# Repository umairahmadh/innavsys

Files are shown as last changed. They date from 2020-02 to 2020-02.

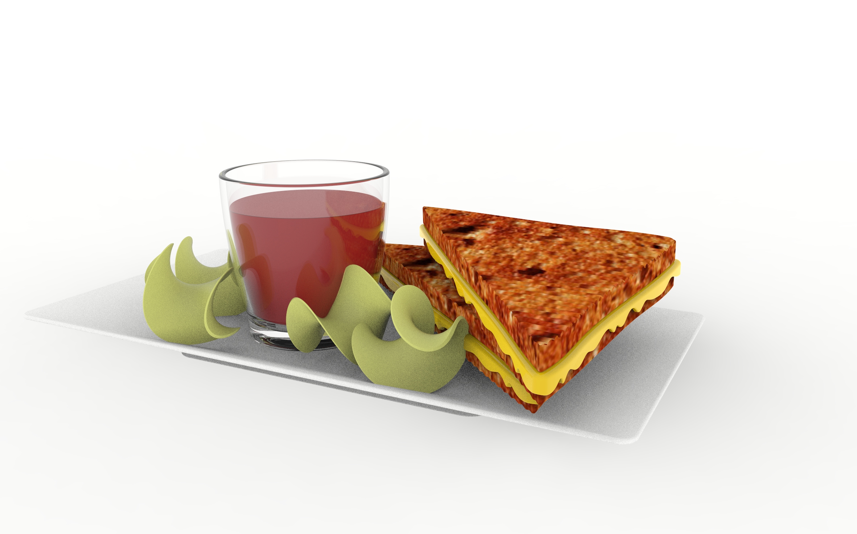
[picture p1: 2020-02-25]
Hardware/Robot_design/grilled-cheese-plate-1.snapshot.2/untitled.37.jpg

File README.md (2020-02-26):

# innavsys
External vision based navigation system for Indoor robots

This project was done for the fulfilment of the degree program "BSc (Hons) Engineering in Electrical and Electronic Engineering" at Faculty of Engineering, South Eastern University of SRi Lanka.

The team was consisting of the following students,
1) G.S. Umair Ahmadh (https://github.com/umairahmadh | https://www.linkedin.com/in/umairahmadh )
2) I.I.S. Premasri ( https://www.linkedin.com/in/imeshsps/ )
3) A.N.F. Mursina Begum ( https://www.linkedin.com/in/mursina-begum-606090127/ )

And the supervisors were,
1) Dr. WGCW. Kumara
2) Eng, Abdul Cadar

Project documentations and descriptions are in reports folder.

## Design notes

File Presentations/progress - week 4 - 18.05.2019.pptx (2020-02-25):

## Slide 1

EE 74099 / EN 74099 Research Project
Project Title: Vision Based Navigation System for Indoor Robots

Progress Presentation – 4
18.05.2019

Under the Supervision of :
Dr. WGCW Kumara
And Eng. Abdul Cadar

Team Members:
ANFM. Begum - SEU/IS/13/EG/002
GSU. Ahmadh - SEU/IS/13/EG/011
IIS. Prema Sri - SEU/IS/13/EG/032

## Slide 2

We are now mainly working in two parts.
1. Hardware build of the robot
2. Navigation System

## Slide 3

As we already reported in the previous progresses, we managed to come to an extent where we are now able to transfer a coordinate from a camera image to a real 2D map.
When we complete the part of detecting and tracking the robots in the image, we will then be able to plot the coordinates on the Map drawn.

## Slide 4

At this point, it requires a lot of reading on Object detection and tracking.
There are many recommended ways to achieve this. Traditional image processing methods are being outperformed by Deep learning.

Now we need to study about the possible methods and to decide on which way to move with.

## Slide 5

Imesh’s proposed design for the Robot will be as follows in the next slides,

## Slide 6

Robot-building…

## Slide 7

- A mobile robot needs locomotion mechanisms that enable it to move unbounded throughout it’s environment.
- Mobile robots generally locomote either using wheeled mechanisms, or using a small number of articulated legs.
- Legged locomotion requires higher degrees of freedom and therefore greater mechanical complexity than wheeled locomotion.
- Wheels, in addition to being simple, are extremely well suited to flat ground.

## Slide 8

- There are four major wheel classes.
  1. Standard wheel.
  2. castor wheel.
  3. Swedish wheel.
  4. Ball or spherical wheel.

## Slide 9

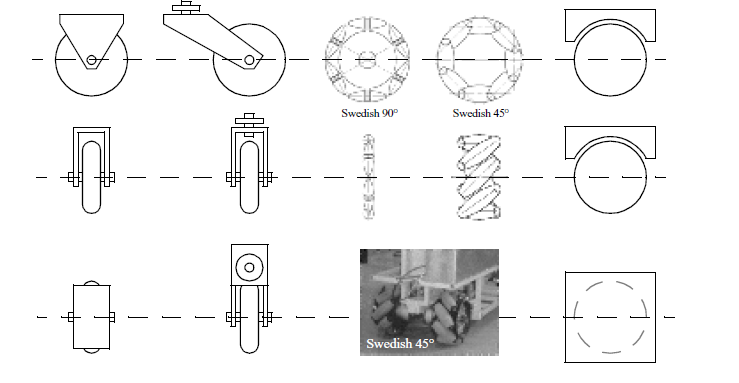
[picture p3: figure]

1

2

3

4

Source : Introduction to Autonomous Mobile Robots - Siegwart Nourbakhsh (Figure 2.19)

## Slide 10

- There is a very large space of possible wheel configurations when considers possible techniques for mobile robot locomotion.
- The choice of wheel types for a mobile robot is strongly linked to the choice of wheel arrangement, or wheel geometry.
- One of the cost effective solution for mobile robot navigation is differential drive systems.

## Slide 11

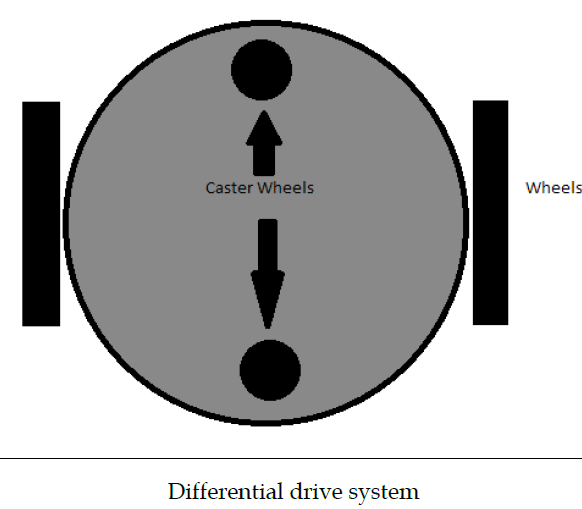
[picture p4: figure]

Source : semanticscholor.org

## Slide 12

- The differential drive robot consists of two wheels mounted on a common axis controlled by two separate motors.
- This drive mechanism is mainly indented for indoor navigation.
- There are two caster wheels ensures the stability and weight distribution of the robot.

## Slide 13

Some of out preliminary works on object detection is in the following few slides…

## Object tracking

Two main procedures are used in object tracking
- Color filtering
- Contour finding

## Steps followed in coding

1. Convert image from BGR to HSV
2. Filter the pixels between minimum and maximum threshold
3. Morphological Operations (Dilate and Erode)
4. Track the (x,y) coordinates of object.

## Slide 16

Original image is converted from BGR to HSV

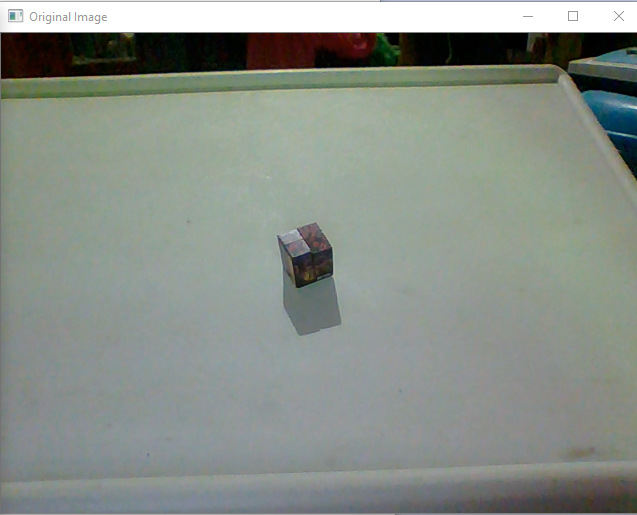
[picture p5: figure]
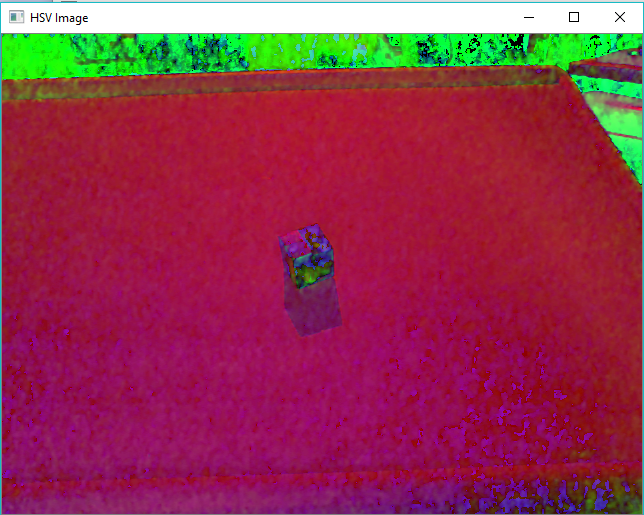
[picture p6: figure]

Figure 1: BGR image

Figure 2: HSV image

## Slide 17

Threshold image is obtained from HSV adjustment

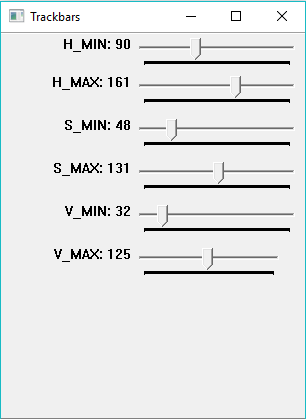
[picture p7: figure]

Figure 2: HSV values

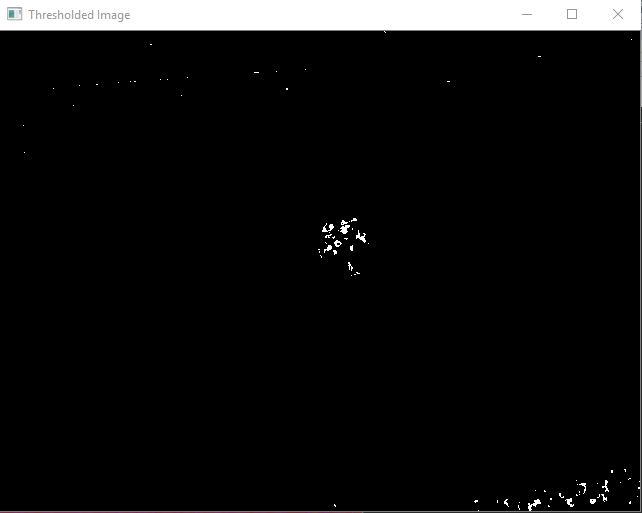
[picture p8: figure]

Figure 3: Threshold Image

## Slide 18

Dilate and erode functions are used to reduce noise

Figure 1: Adjusted HSV values

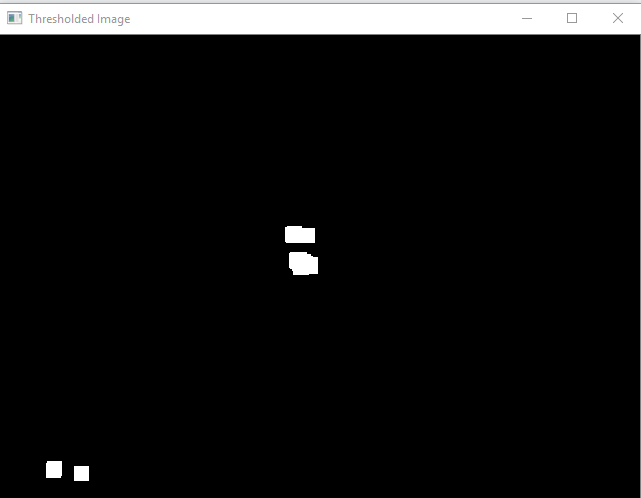
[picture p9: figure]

Figure 1: Threshold Image after morphological operations

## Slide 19

Object is tracked by largest contour

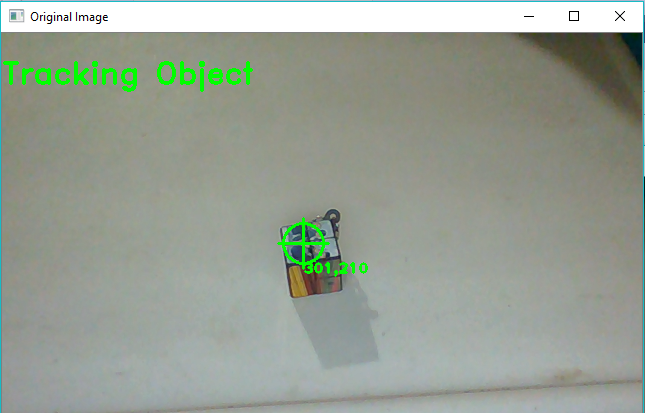
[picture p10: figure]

Figure 4: Tracked object

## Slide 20

Thank You

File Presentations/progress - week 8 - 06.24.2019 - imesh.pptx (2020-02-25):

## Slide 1

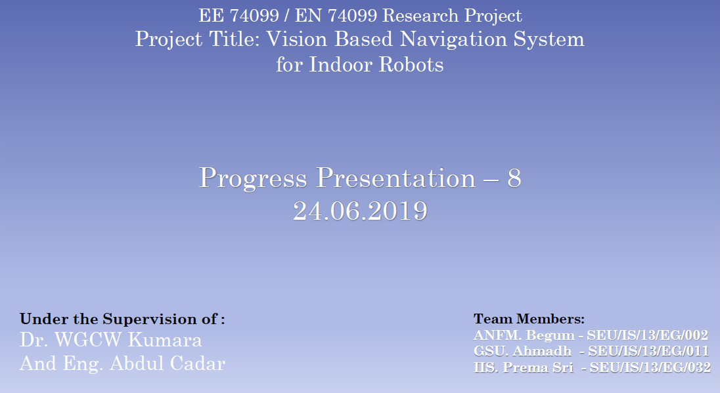
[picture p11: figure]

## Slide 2

This week we worked on,
- Designing Robot model
- Total Weight estimation
- Idea for Path planning based on External camera
- Mapping and Navigation with ROS

## Designing Robot model

- We did a Solidworks model for the Robot design we are planning to build.
- For the plates we decided to go with Aluminum Composite Material boards because of their strength and light weight.
- To connect plates we will be using threaded rods covered by aluminum tubes.

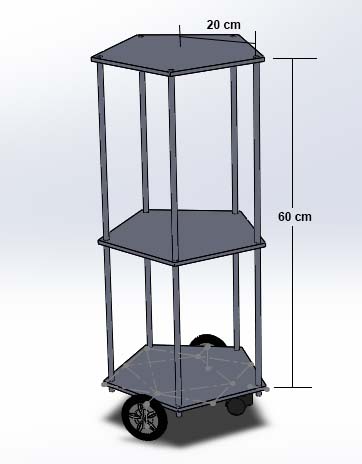
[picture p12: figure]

## Total Weight Estimation

Item | Weight
ACM Board for 0.378 m² area | 1.52 kg
Threaded rods for 3.5 m | 2.2 kg
Kinect | 0.6 kg
Aluminum tubes | 0.4 kg
Wheels | 0.6 kg
Power Bank and Battery | 1.0 kg
Motors (NEMA 23) x 2 | 1.4 kg
Other Electronics | 0.5 kg
For foods | 1.0 kg
Total Weight | 9.22 kg

## Calculation of motor torque

- In our design we have 4 wheels and 2 motors.
- Here we assume that the coefficient of friction is 0.6 and radius of wheel is 5 cm.
- The weight acting on the four wheels can be written as,

- N1 is the weight acting on each caster wheel.
- N2 on each motor wheel.

2 ∗ N1 + 2 ∗ N2 = Total Weight

The maximum torque is required when the robot starts moving. It should also overcome friction.
To calculate the maximum torque (T),

μ ∗ N ∗ r − T = 0

- μ is the coefficient of friction.
- N is the average weight acting on each wheel.
- r is the radius of wheels.
- T is the torque.

## Calculation of motor torque

- Assuming that the weight of the robot is equally distributed on all the four wheels,

N = mg / 4

=22.6 N

=9.22 kg ×9.8ms^(−2) / 4

Motor torque required,

T = 0.6 ∗ 22.6N ∗ 0.05 m

= 0.678 N m

## Idea for Path planning based on External camera

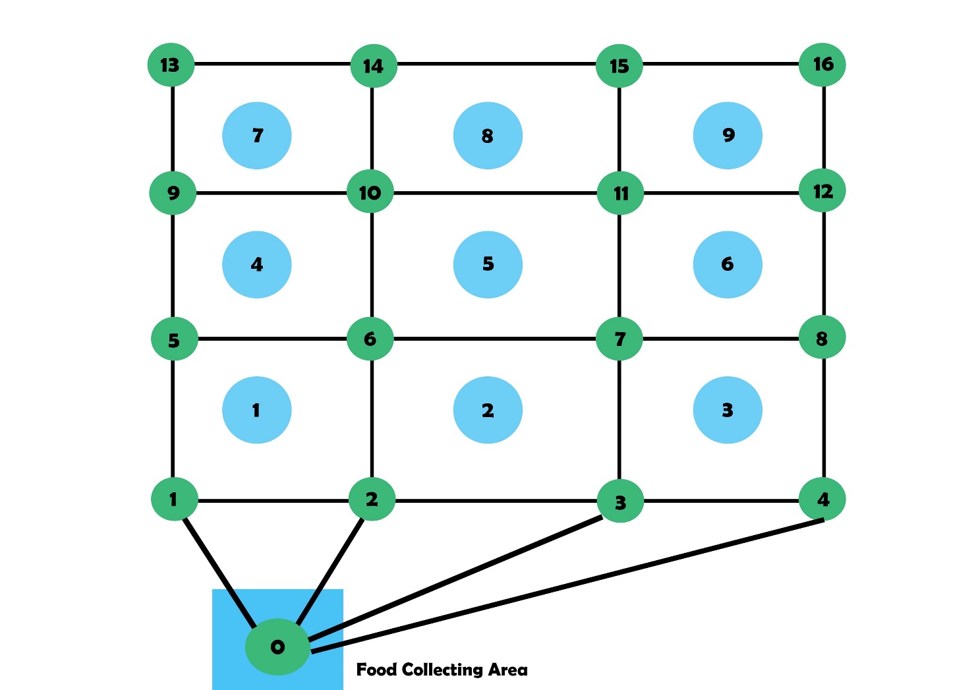
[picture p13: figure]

## Idea for Path planning based on External camera

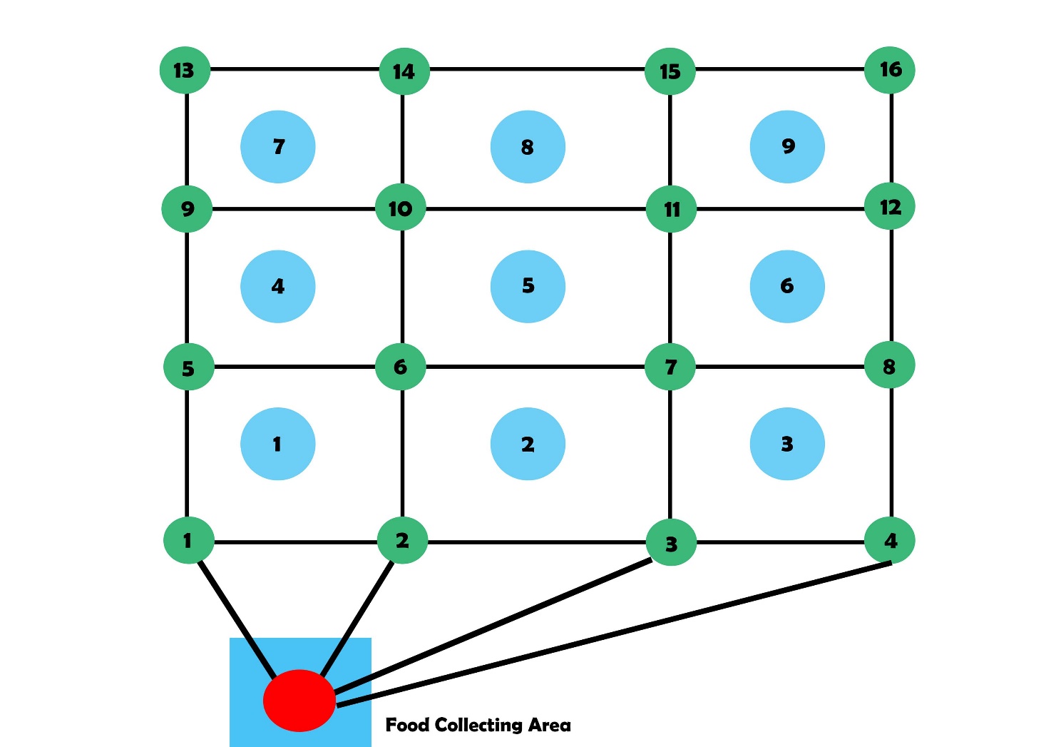
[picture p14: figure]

## Idea for Path planning based on External camera

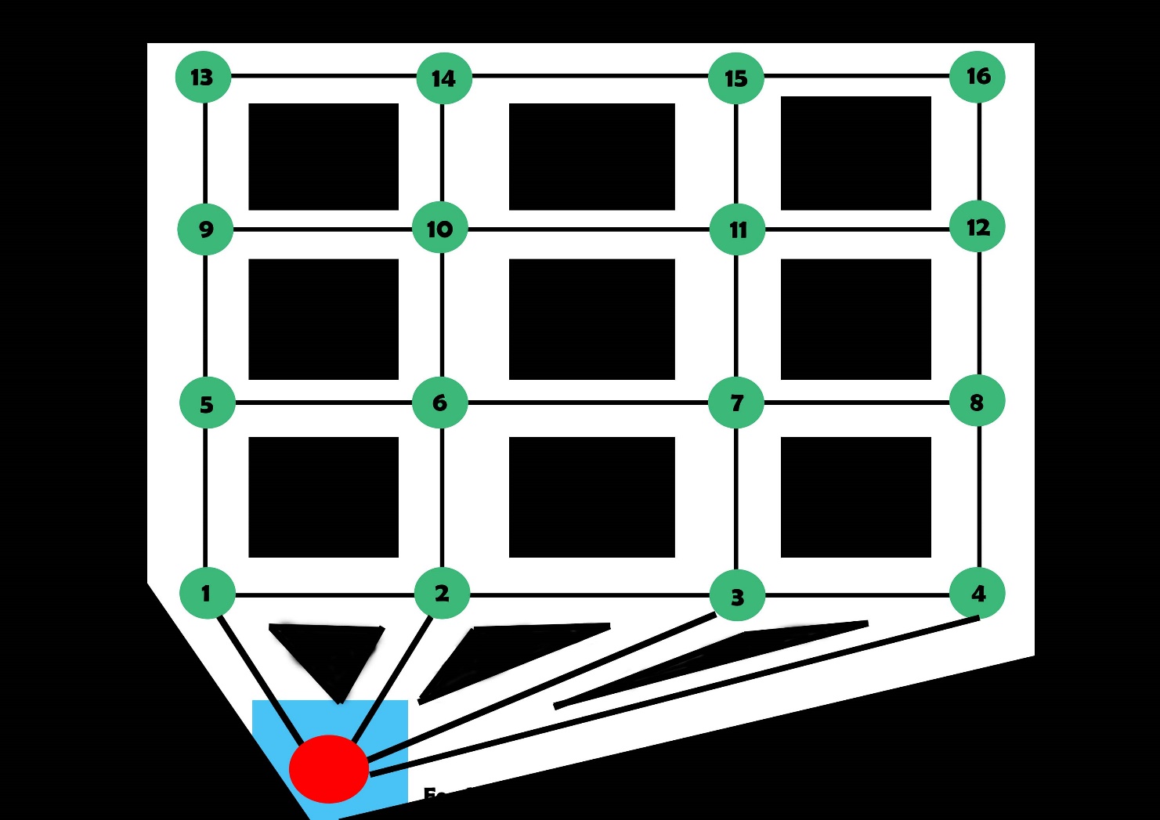
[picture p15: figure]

## Idea for Path planning based on External camera

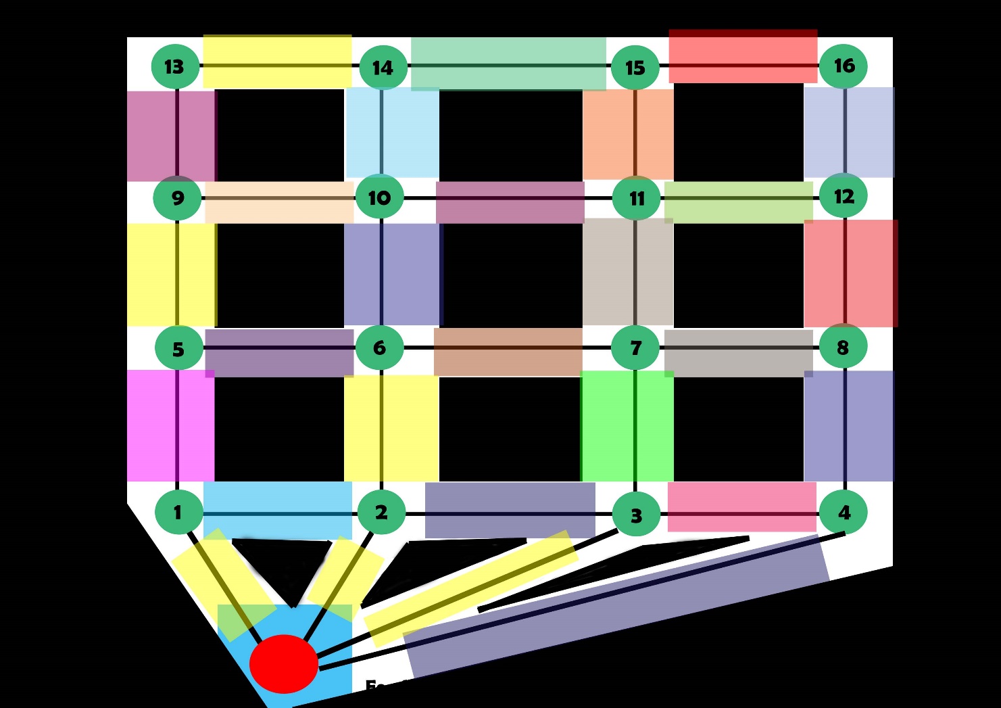
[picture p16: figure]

## Idea for Path planning based on External camera

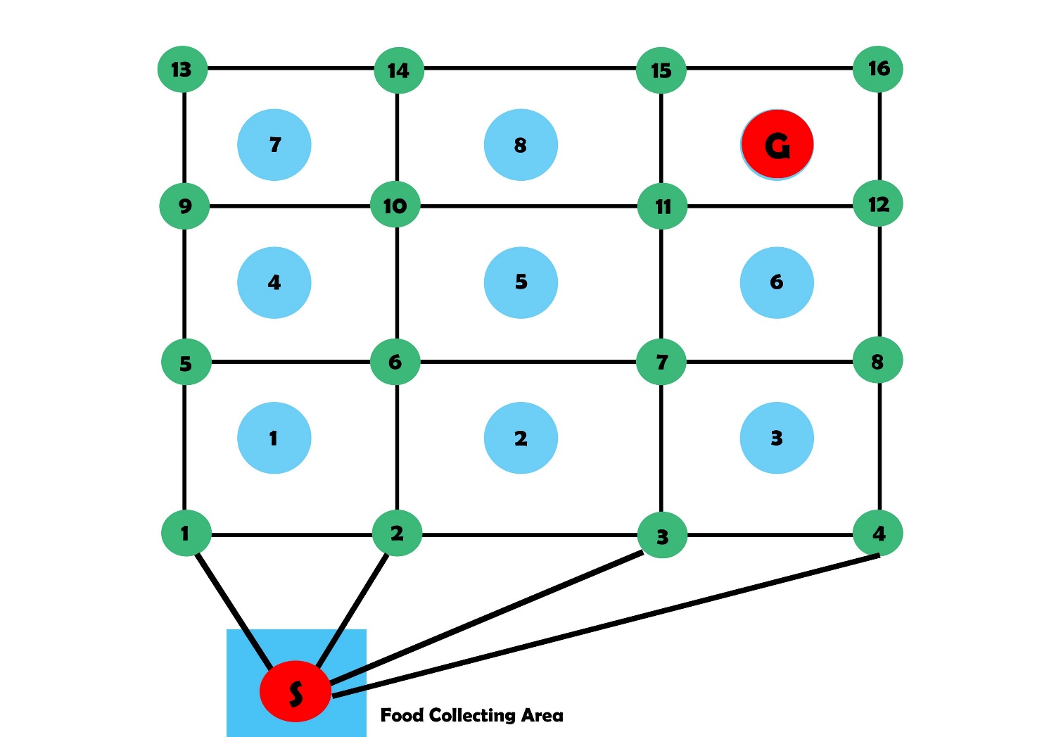
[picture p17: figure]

## Idea for Path planning based on External camera

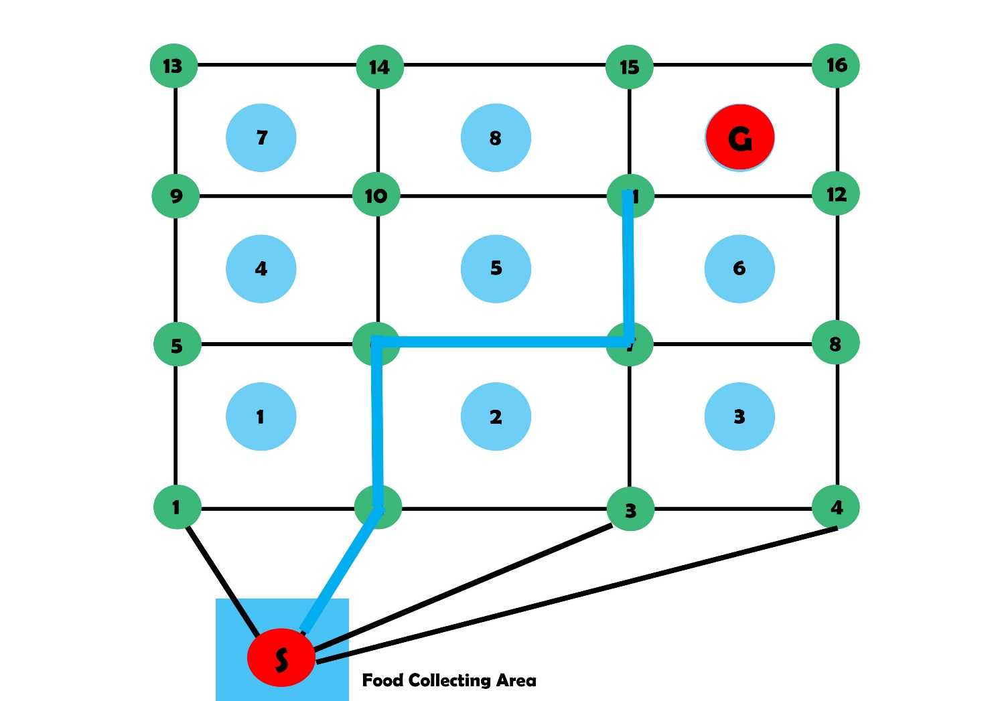
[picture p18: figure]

## Idea for Path planning based on External camera

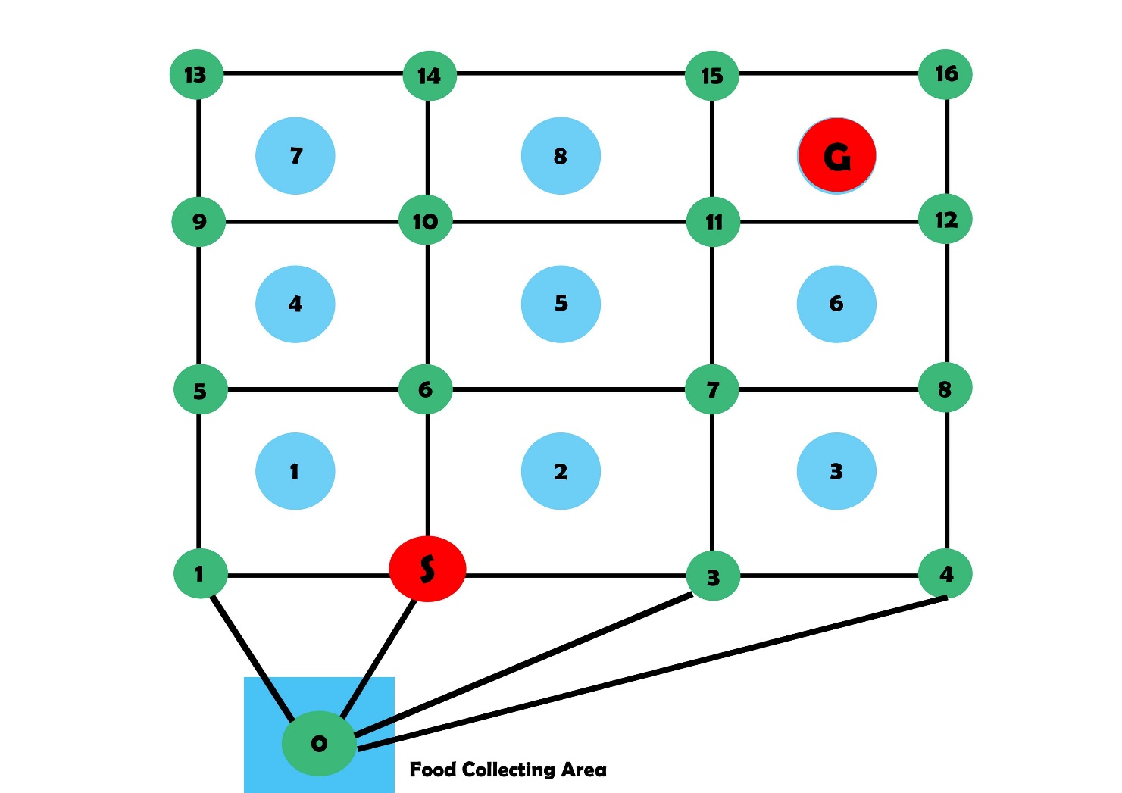
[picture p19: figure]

## Idea for Path planning based on External camera

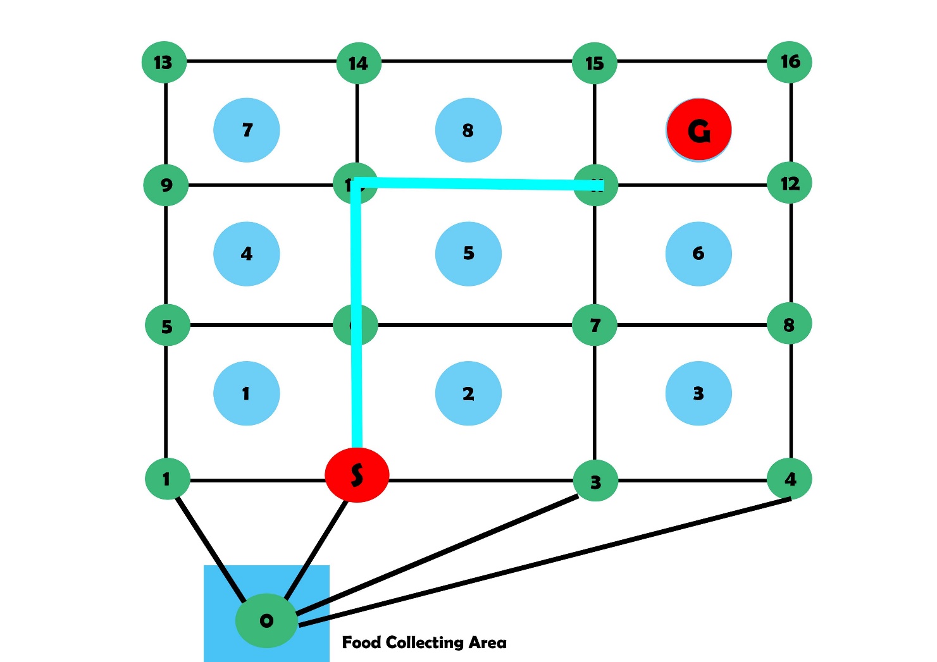
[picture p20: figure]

## Idea for Path planning based on External camera

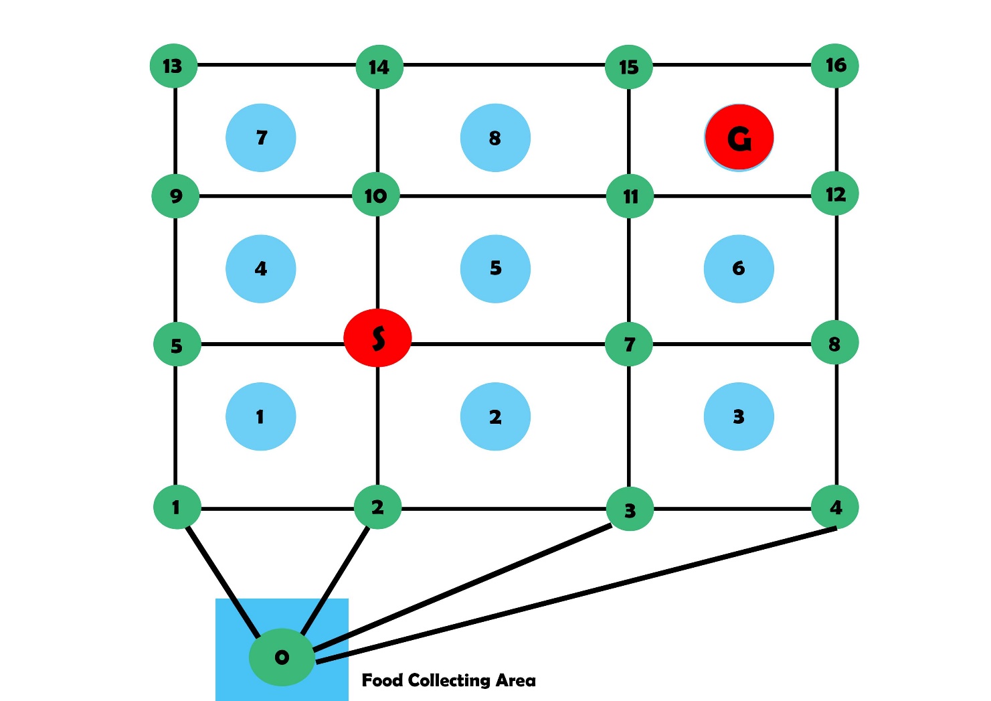
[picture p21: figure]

## Idea for Path planning based on External camera

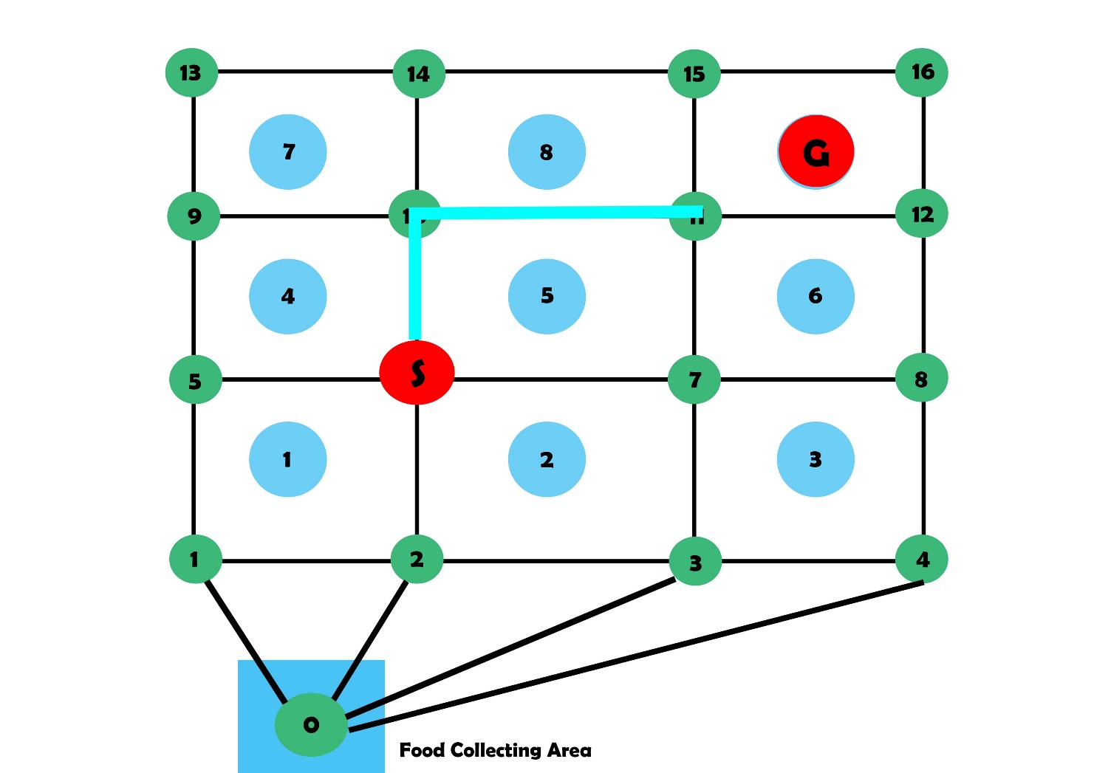
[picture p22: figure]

## Idea for Path planning based on External camera

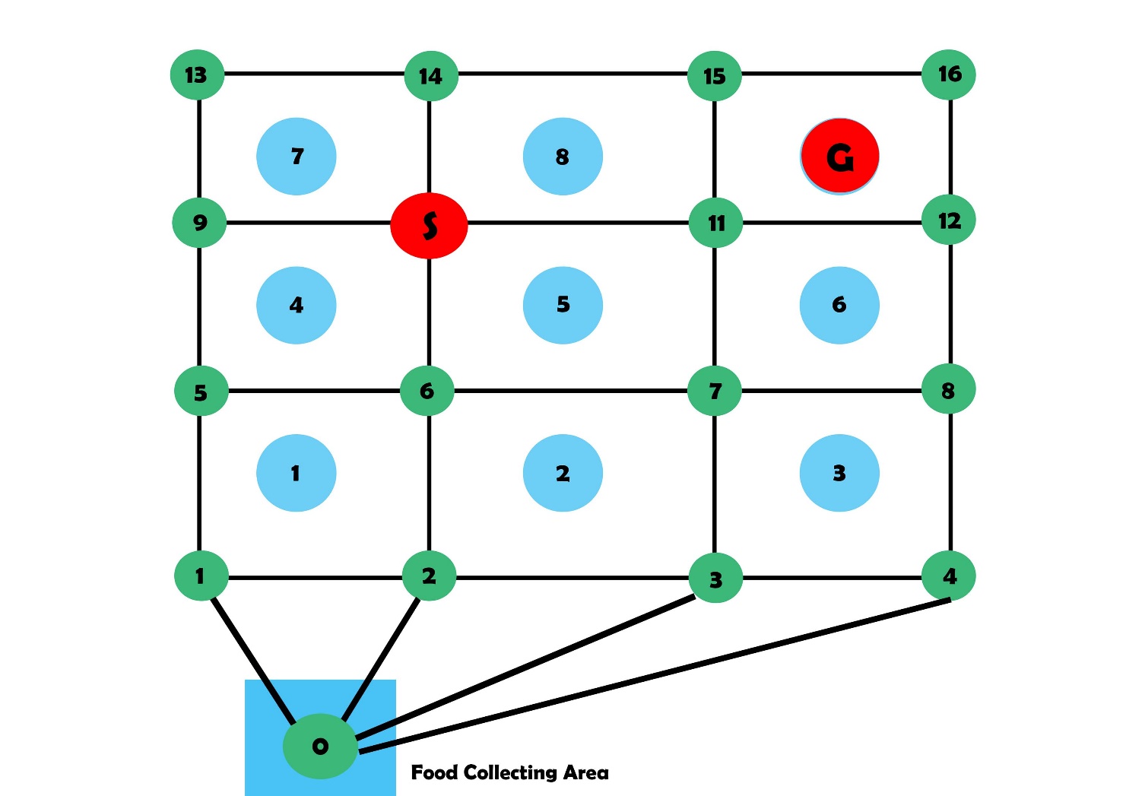
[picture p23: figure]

## Idea for Path planning based on External camera

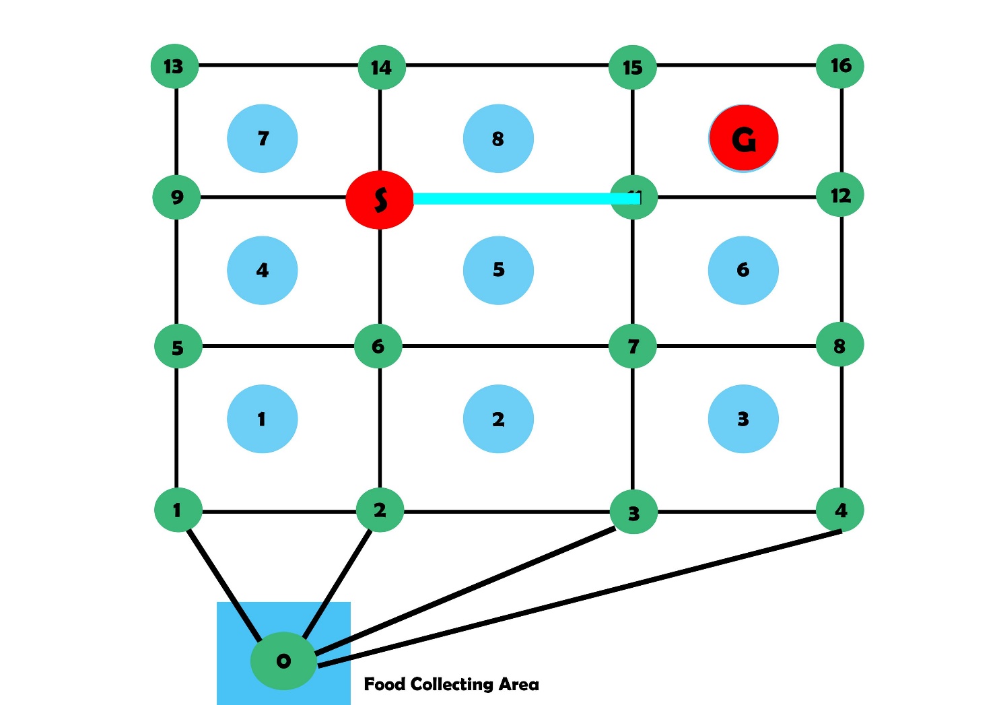
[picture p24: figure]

## Idea for Path planning based on External camera

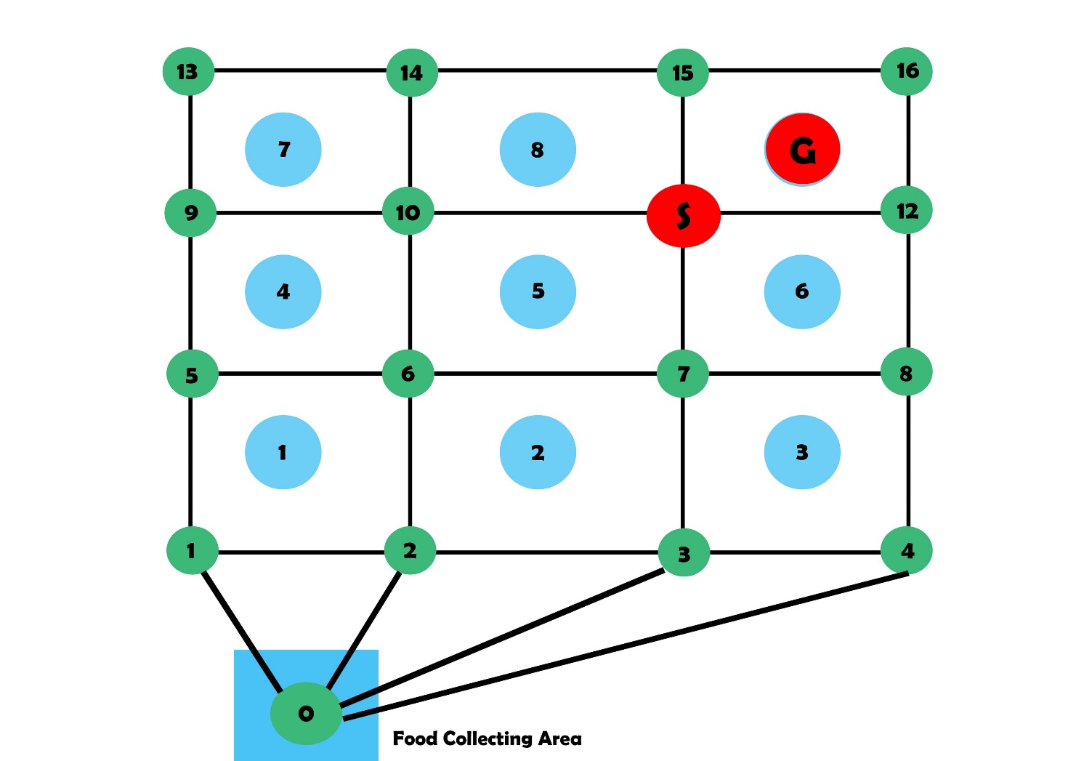
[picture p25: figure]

## Mapping and Navigation with ROS

- https://youtu.be/u9l-8LZC2Dc

## For Next Week..

- Buying items and start building the robot
- Recording footages of canteen
  - Stitching images from multiple camera
  - Tracking moving objects on the path
  - Plotting the tracked objects to the map and do path planning for the robot
- UI design and Database schema for Order management system
  - Implementation of the system on a local web server

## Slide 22

Thank You

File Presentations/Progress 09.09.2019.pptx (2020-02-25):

## Phase 1: Hardware build of the robot

Progress - 09.09.2019

Team:
ANFM. Begum - SEU/IS/13/EG/002
GSU. Ahmadh - SEU/IS/13/EG/011
IIS. Prema Sri - SEU/IS/13/EG/032

## Last meeting:

- We agreed to work on finishing the robot hardware as it is important to continue other parts of the project.
- We managed to finish the robot skeleton and making wheel alignments with the motor. Due to exams, we didn’t get to work on motor controlling and the electronics of it.

## Robot building

1. Building shaft and coupler for wheel-motor connection

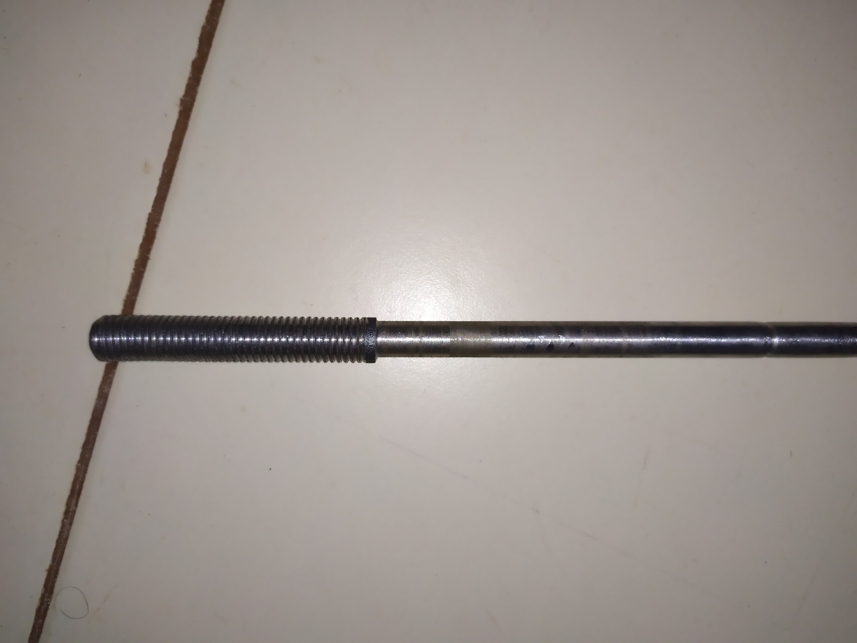
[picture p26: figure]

## Robot building


2. Selection and purchasing of the wheel and connection
3. Adding pair of bearings for the shaft alignment and support
4. Mounting them to the robot body

## Robot building


5. Caster Wheel selection and purchasing
6. Mounting the wheels to the body with spacer nuts to align with the wheel height

## Robot building


7. Connecting the entire skeleton and completing the body
Note: Image here is the initial built of the robot. Later we did motor upgrade and wheel changes, unable to get the final image.

## Next progress:

- Already gathered robot electronics will be connected to the body and we will make the controls.
- By having a wireless control to the robot, any movement commands sent to the robot will be programmatically analyzed and the motor control will be done. (As in our entire system, navigation system will send the movement commands and the robot will only receive which directing and how long it should move. All other coordinate process is to be handled by our external navigation system

## Some interim progress on the electronics


## Thank You

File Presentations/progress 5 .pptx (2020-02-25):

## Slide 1

EE 74099 / EN 74099 Research Project
Project Title: Vision Based Navigation System for Indoor Robots

Progress Presentation – 5
16.05.2019

Under the Supervision of :
Dr. WGCW Kumara
And Eng. Abdul Cadar

Team Members:
ANFM. Begum - SEU/IS/13/EG/002
GSU. Ahmadh - SEU/IS/13/EG/011
IIS. Prema Sri - SEU/IS/13/EG/032

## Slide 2

Design for the robot
Detection and tracking of the robot

1

2

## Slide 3

Design for the robot…

## Robot chassis design

- The design we choose should be able to hold electronics components such as microcontrollers, sensors, battery and hold food we need to deliver.
- One of the easiest designs to satisfy these requirements is TurtleBot, which has kind of table-like design.

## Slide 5


- It has three layers in the chassis.
- A robot platform called Roomba is the drive mechanism of this platform.
- We are planning to design a robot similar to this with our own moving platform and components.
- Moving platform will be designed as a differential drive system.

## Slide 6

Tracking of Robot
Using Object Detection

## Tracking of Robot

- For the navigation of the robot, we need two things.
  1. Object Detection : To identify the current position of the robot
  2. Tracking the path : To track the movements of robot to make sure it is aligned to the commands that being sent to it to reach the target destination.


## 1. Object Detection

- We need to use object detection in our project to achieve two things.
  I. Get the location of the robot in the map to help localize robot in the environment.
  II. Identify people in the environment to decide on the best path for the robot to reach the destination.
- At first step, we are planning to start working on identifying robot in a video feed and get the location in the image. And the detection of the moving objects will be proceeded later on the course.

## 1. Object Detection

- For Object detection,
  - Currently we are experimenting with different methods.
  - Deep learning based object detection is the first one that we are going to go with.
  - In order to do the detection, we need to train a neural network with many images of the robot to identify it on the image feed.
  - As we currently don’t have a robot we thought to go with a simulation images to train it and to test the detection and hence the tracking in the video generated from the simulation.

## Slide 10

- To achieve real-time object detection, we’ll need to..
  - Access video stream in an efficient manner.
  - Apply object detection to each frame.
- Accessing video stream is possible with OpenCV.
- To achieve object detection, we need to train an image classifier.
- Then we can use trained classifier to detect objects in an image, and to track them across a video.

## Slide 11

- we are going to test an image classifier with the images we have from simulation model for the TurtleBot robot from Gazebo robotics simulator.


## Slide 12

Next Week…

## Next Week

- We will be working on training a neural network with images gathered from the simulation environment.
- After successfully completing the training, we will then work on integrating the detection to OpenCV to get the coordinates of the robot on the image.
- Then, converting the image coordinates to world coordinates using our previously done works. So that we will have a tracking on a 2D map.

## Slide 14

Thank You

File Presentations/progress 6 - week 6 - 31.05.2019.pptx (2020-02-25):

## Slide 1

EE 74099 / EN 74099 Research Project
Project Title: Vision Based Navigation System for Indoor Robots

Progress Presentation – 6
31.05.2019

Under the Supervision of :
Dr. WGCW Kumara
And Eng. Abdul Cadar

Team Members:
ANFM. Begum - SEU/IS/13/EG/002
GSU. Ahmadh - SEU/IS/13/EG/011
IIS. Prema Sri - SEU/IS/13/EG/032

## Object detection using deep learning

- Predict the object along with the class is called object detection.
- From object detection we can predict class and bounding box’s coordinates. Using those coordinates, we can identify the location of object.


Figure 1: Objects with their label and bounding box

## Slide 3

To detect the image using classification, below steps will be followed
1. Train a multi-label classifier
2. Take windows of fixed sizes from input image
3. Feed the windows to the image classifier to further process.
- There are various object detection methods,
1. SIFT
2. HOG features
3. R-CNN
4. YOLO
5. SSD

## Object detection with SIFT feature extractor

- Stands for Scale Invariant Feature Transform
- We can work with single sample image in SIFT.
- Steps followed to get object detection
1. Get features from training image(sample image) and query image(live image from camera)
2. Match the parameters of both images which are extracted by SIFT(). We can set minimum match count.
3. If we get good matches, create a border around the object.

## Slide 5


Figure 2: Train Image


Figure 3: Query Image

## Video object tracking

- We can’t use object detection in each frame when image has multiple objects. Connecting the objects in the frames will be difficult for it.
- Also if the object goes out of the camera view, we can’t detect and ensure the same object.

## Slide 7

- Object tracking process consists four components,
1. Target Initialization
We have to define the starting point of the target by drawing a boundary around it
2. Appearance Modelling
We need to know about material and visual features
3. Motion estimation
Predict the zone where the object will be presented in next frames
4. Target positioning
Use motion estimation’s region to get the exact location of object
- Most popular deep learning based approaches
1. MDNET
2. GOTURN
3. ROLO

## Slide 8

Currently we are learning and experimenting various methods to be used in detecting and tracking our robot.
Accuracy and robustness of the system is very crucial here as our main navigation system is going to based on this.
We will be updating on the methods we tested and our conclusion about the usage of the system to our purpose in due course.

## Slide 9

Thank You

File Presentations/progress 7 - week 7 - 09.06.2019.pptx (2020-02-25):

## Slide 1

EE 74099 / EN 74099 Research Project
Project Title: Vision Based Navigation System for Indoor Robots

Progress Presentation – 7
09.06.2019

Under the Supervision of :
Dr. WGCW Kumara
And Eng. Abdul Cadar

Team Members:
ANFM. Begum - SEU/IS/13/EG/002
GSU. Ahmadh - SEU/IS/13/EG/011
IIS. Prema Sri - SEU/IS/13/EG/032

## Progress on object detection and tracking

From various methods available for object detection, we experimented the following methods and concluded the possibility of their usage for our purpose.
1. SIFT
2. GoTurn

## SIFT

- Stands for Scale Invariant Feature Transform
- We can work with single sample image in SIFT.
- Steps followed to get object detection
  1. Get features from sample image and query image
  2. Match the parameters of both images which are extracted by SIFT(). We can set minimum match count.
  3. If we get good matches, create a border around the object.

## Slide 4


Figure 2: Train Image


Figure 3: Query Image

## Issues in SIFT

- Even though it is a good method to detect presence of an object in an image frame, it can only be used for fixed object as it detect based on feature matching. When the object’s orientations get changed, detection fails severly.
- Thus, this method failed to get enlisted in our To-be-used list.

## GOTURN

Following explanation is an excerpt from https://www.learnopencv.com/goturn-deep-learning-based-object-tracking/

- GOTURN, short for Generic Object Tracking Using Regression Networks, is a Deep Learning based tracking algorithm.
- Most tracking algorithms are trained in an online manner. In other words, the tracking algorithm learns the appearance of the object it is tracking at runtime.
- Therefore, many real-time trackers rely on online learning algorithms that are typically much faster than a Deep Learning based solution.
- GOTURN changed the way we apply Deep Learning to the problem of tracking by learning the motion of an object in an offline manner. The GOTURN model is trained on thousands of video sequences and does not need to perform any learning at runtime.

## GOTURN Architecture


Figure shows the architecture of GOTURN. As mentioned before, it takes two cropped frame as input. Notice, the previous frame, shown at the bottom, is centered and our goal is the find the bounding box for the current frame shown on the top.
Both frames pass through a bank of convolutional layers. The layers are simply the first five convolutional layers of the CaffeNet architecture. The outputs of these convolutional layers (i.e. the pool5 features) are concatenated into a single vector of length 4096. This vector is input to 3 fully connected layers. The last fully connected layer is finally connected to the output layer containing 4 nodes representing the top and bottom points of the bounding box.

## Issues in GOTURN

- After successfully setting up our system to work with GOTURN, we experimented it on a live feed of webcam to track few objects. And following are the issues we found to be on our way of choosing this for our purpose.
1. This method is a pre-trained method. It has a set of objects already trained. When we track a new object it works fine as long as the frame doesn’t come across a known object to the network. For Example, this is very good with face tracking. When we try to track the palm, it tracks very well until the palm passes the face. When the tracking box passes the face, it sticks to the face and start tracking the face.
2. Stops tracking when object go out of frame
3. Accuracy of tracking was very limited for new objects.

## Next,

- We decided to train our detection network and experimenting the success rate. Based on which we will choose a method to carry on with the process.
- Now, we are setting up YOLO object detection method and training our custom object classifier with it with the help of Tensorflow.
- As it requires a lot of processing power and thus time for training object detection neural network and other dependencies to be installed on the system, we are setting up our pc to do the experiment.
- Later on, once the training is done, we will test it on a simulator video.

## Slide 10

Thank You

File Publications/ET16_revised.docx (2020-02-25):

# VISION BASED INDOOR NAVIGATION SYSTEM USING EXTERNAL CAMERA MOUNTED ON ROOM

G.S.U. Ahmadh¹, I.I.S. Premasri¹, A.N.F.M. Begum¹, M.F.M. Abdul Cader¹
and W.G.C.W. Kumara²

¹ Department of Electrical and Telecommunication Engineering, South Eastern University of Sri Lanka, Sri Lanka

² Department of Computer Science & Engineering, South Eastern University of Sri Lanka, Sri Lanka

umairahmadh@seu.ac.lk

ABSTRACT: It is vital to have a very good path planning for self-navigating mobile robots. Having considerations of the environment and objects in the space is a key in achieving a safe and effective path for robots. In indoor environments, objects and the environment are unpredictable, unlike that of in the road navigation where there are standard guidelines and road symbols. To overcome this issue, existing applications provide solution to a certain extent. Indoor positioning systems based on Infrared, Wi-Fi and other similar techniques are existing in the industry. Also, there are solutions providing such systems with the use of camera on the robot. Although such systems deliver the positioning of the robot and thus generating a path based on it, they fail to have an overall view of the entire space so that the generation of the path is more effective. To overcome this, the paper discusses here, a solution of centralized vision based navigation system for indoor robots. Our solution takes a view of the entire space beyond the immediate surroundings to the robot which was the only concern of previous solutions existing. By such view, our solution can plan a path for the robot more effectively as it has all the objects in the space into consideration.

# Keywords: Robotics, Computer Vision, Path Planning, Indoor Navigation, Vision Based Navigation

1. INTRODUCTION

Path planning and navigation of autonomous robots and vehicles have always been one of the mostly researched areas in robotics and automobile industry. Giving the autonomous robots a power to navigate to their target destination without having a collision with other objects or navigating in a wrong path is a very essential task. Even though this is a common concern in all types of autonomous vehicles, Indoor robots are more prone to errors in navigation unlike in outdoor environments, because of their configuration space is not typical and also the obstacles are mostly unpredictable. The number of indoor robots like restaurant service robot, elder care robots and room cleaning robots is increasing to take their places everywhere from household to industrial workplaces. Although most of the existing indoor robots are manually guided or preprogrammed to follow a fixed path, nowadays autonomous navigation robots are coming into the market. To achieve the autonomy in navigation few of them have cameras to see their immediate surroundings and some have range sensors to detect immediate obstacles to improve their navigation. These navigations methods that utilize in-built camera or other sensor-based are mostly ineffective as none of them give the robots an insight of what's beyond their line-of-sight. Having such ability to do the navigation, based on the real-time condition of the entire configuration space would give an advantage to the system of being more effective and faster path planning and navigation.

In order to achieve such system, this paper presents an approach that will make use of cameras mounted on top of the room to get an oversight of the entire room and by utilizing them, the robot will be able to get a map of the entire room by processing the captured image and generating an obstacle map. From the map, the system will then be able to generate a path for the robot from its current destination to the target destination. For this purpose of path planning, a path planning algorithm named "Extended rapidly exploring random tree (RRT*)" has been chosen to be used for the purpose after exploring various available algorithms (Noreen, Khan, and Habib, 2016).

Rapidly exploring random tree (RRT) (Lavalle, 1998) provides a quick solution to generate paths with having no necessity of defining grids and nodes unlike in other shortest path algorithms like Dijkstra. Among all the probabilistic planning algorithms, RRT has become the most preferred algorithm for path planning due to its speed and simplicity. RRT generates a tree between starting and target nodes by creating nodes at random points and finding the nearest node and adding it to the tree. It creates and adds matching nodes to the tree until a branch of the tree meets the goal node.

The extended version of RRT named as RRT* provides an additional feature of Rewiring the tree. It gives the algorithm a possibility of recreating the nodes dynamically. The paper by Connell and Manh La (2018) is providing an explanation of how the RRT* algorithm can be optimized for dynamic obstacles in the environment. In this paper, our approach is to use RRT* in a real environment to navigate an indoor robot by detecting dynamic obstacles in the environment using external cameras. In addition to that range sensors will be mounted on the robot to detect immediate obstacles and to request for the regeneration of the tree if any immediate obstacles found.

1.1 Literature Review

There are several methodologies proposed in the literature about mapping and path planning. Mapping should be done in order to find the robot environment, which can be acquired by either constructing occupancy grid maps or landmark maps. To create the model of the environment, the information can be collected by either a variety of onboard sensors or external sensors such as surveillance camera and the external GPS system.

Depends on the status of environment whether it is known or unknown, the mapping technique will vary. For indoor mobile robot navigation, typically the environment is known. Li et al. (2014) presented a technique in which the experimental map was created using a vision-based system. In this paper, they used captured images using external webcams. Image processing technique has been taken with these captured images which include a greyscale, a background subtraction, a morphological image processing, and a connected component labelling technique. Then the coordinates were defined in the image domain (“Mapping Camera Coordinates to a 2D Floor Plan,” n.d.).

For the unknown environment, a well-known algorithm called Simultaneous Localization and Mapping (SLAM) is needed for many applications now. It is a process of creating a map which navigates the robot in its environment while using the map it generates. Milford and Wyeth (2010) presented a new system for integrating continuous Simultaneous Localization and Mapping (SLAM) with autonomous behaviors and a system of map maintenance. They experimented their results to demonstrate the use of the entire system in live delivery over a two-week period across two different office buildings.

In this paper, they used RatSLAM, a bio-inspired Simultaneous Localization and Mapping (SLAM) system to localize, map and navigate throughout the robot’s lifetime. They investigated the static mapping problem based on how the animals forage and identify their home with the change of activity of other animals, weather and season. Main components of persistent navigation and mapping system are core RatSLAM system, the navigation system, and robot task selection. The global experience map is created by RatSLAM which is a resource to plan paths to locations that are beyond the range of the robot’s sensors. The local obstacle map is a resource that captures the relevant aspects of the environment within the immediate range of the robot’s sensors.

Path planning is another important task of finding a continuous path that will drive the robot from the start to the desired target location. There are several studies found in the literature. Khanmirza et al. (2017) proposed a comparison of seven mostly used deterministic and probabilistic path planning algorithm which are A*, Dijkstra, Visibility Graph, Probabilistic Roadmap, Lazy Probabilistic Roadmap, Rapid-exploring Random Tree, and Bidirectional Rapid-exploring Random Tree in 19 different environments with different working conditions to evaluate the best path planning algorithm. Path planning techniques can be analyzed into three groups,

1. Deterministic algorithms: suitable in the case of a robot which has few degrees of freedom and deals with the 2D environment.
2. Probabilistic algorithms: preferable in the case of high dimensional space
3. Heuristic algorithms: deals with complex path planning problems.

The deterministic algorithm takes consideration with a weighted directed graph while probabilistic use the random sample points to get the nodes to move the robot. In this paper, they only presented the study of deterministic and probabilistic algorithms since the heuristic algorithm has been researched in several studies nowadays. The performance of algorithm is characterized by several objectives such as path length, the path smoothness, the runtime, and the planning success rate. By comparing the objectives to test the performance of each algorithm, dimensionless plots are used. In the visibility graph, shortest and smoothness path were received while in the Bidirectional Rapid-exploring Random Tree (B-RRT) achieved highest success rates. In recent research (Connell & Manh La, 2018), the Extended Rapid-exploring Random Tree (RRT*) is proposed with greater optimization compared with the general RRT algorithms.

2. METHODOLOGY

Our methodology is to have the following approaches

1. Capturing and processing the images of the room with cameras mounted on the top of the room,
2. Detection of objects in the room and classifying of moveable paths and obstacles,
3. Generating the path for the robot to its destination using the RRT* algorithm and
4. Regeneration of path when a new obstacle is introduced in the previous path

Based on these approaches an algorithm will be developed to implement this in an indoor system. The dataflow is shown in Figure 1.


Figure 1: Data flow of the system methodology

2.1 Capturing and Processing the Images of the Room

A fisheye lens camera will be mounted on top of the room to cover a wide area. Images captured from the camera will be having distortions throughout the images. In order to get a fixed and a proper image calibration is needed. A standard method of calibration is to use a known size of the chessboard to get the camera intrinsic and extrinsic parameters and thus correcting the image distortions. Figure 2 shows the captured image with distortion.

WhatsApp Image 2019-07-26 at 21

Figure 2: Captured Image of Cafeteria Which Has Distortion in the Edges (Left) and Image of the Cafeteria After Calibration (Right) (This Will Be Used for Further Processing).

From the calibration process, a matrix is generated and is used for further operations. After calibration, the above image shows the corrected and a plain image of the cafeteria. The calibration matrix will be applied to all the processed images throughout all further applications.

2.2 Detection of Objects in the Room and Classifying of Moveable Paths and Obstacles

Once the undistorted image of the room is achieved, then the objects in the room need to be identified in order to get a view of moveable path to allow the path planning algorithm to generate its paths in such a way it doesn’t go through any obstacles.

There are two kinds of objects in the room.

1. Fixed objects like furniture and pillars
2. Dynamic objects like human

Firstly, the captured image on which there was no presence of any dynamic objects was run through image segmentation by clustering and then a cost map was generated and based on a threshold it was turned into a binary image marking objects as black and the moveable area as white (Figure 3).


Figure 3: Detected Fixed Objects and Marked Them into a Binary Image.

But as this image was having inner white space between parts of objects which may be assumed by our path planning algorithms as a moveable path area, these spaces needed to be blacked out. For this purpose, detected objects were needed to be bounded into a contour.

And as in a real environment, there will be moving objects. In order to give the robot a path, all objects in the environment at the time of generating the path need to be considered. To do so, the reference background image (Figure 4) will be used for identifying moving objects on top of it. The same process which was used in the above background reference generation was used here on top of this reference for this purpose.


Figure 4: Image After Applying Contour


Figure 5: Image with New Objects on The Left and a Binary Image After Detection of All Objects in the Environment.


Figure 6: Starting Point and Possible Destination Points Are Marked on the Map.

  2.3 Generating the Path for the Robot to Its Destination Using RRT* Algorithm

Once the objects and moveable area in the environment are detected, now the path needs to be generated. For this purpose, the starting and destination nodes need to be defined. In a real application, it should be definable by the end user. In this application, those nodes are defined and used to generate the path.

Using this map, according to the user desired destination, the robot will get the path generated from the navigation system. The navigation system uses Extended Rapidly Exploring Random Tree (RRT*) for generating a path. Even though this doesn’t give an optimized path, this algorithm allows us to work with a dynamically varying environment where path generation needs to be re-done according to the moving obstacles.


Figure 7: Image Showing the Generated Path from the Robot Starting Point and To One of The Possible Delivery Points

Once this path is generated, it is transmitted to the robot and thus the robot follows the path. A built-in range sensor in the front of the robot will keep looking for any sudden obstacles come to collide on it. To avoid the collision, the robot will stop moving if there is an object on its path. Once there is an obstacle on its path and it can’t move forward, the robot will allow a waiting period to check whether the object is moving away from the path. If not, the robot will need a new path and it requests the system for a new path.


Figure 8: Robot Stops When There Is A Sudden Obstacle Comes on Its Path. Robot Waits and Request A New Path.


Figure 9: Ultrasonic sensor detects an immediate obstacle in the front (Anila, Saranya, Kiruthikamani, and Devi, 2017)

  2.4 Regeneration of Path When a New Obstacle Is Introduced in the Previous Path

A regeneration of path is done by simply changing the start point to the current position of the robot and generating the path again based on current parameters. And the newly generated path will be transmitted to the robot.

When the request for a path generation is received by the system it goes through all the previous processes of detecting obstacles and generating the binary image of obstacles and moveable area. The following image (Figure 10) shows the regeneration of path.


Figure 10: Newly Generated Path Based on the Current Environment Configurations.

3. CONCLUSION AND FURTHER IMPROVEMENTS

In this paper, the authors presented an external camera based indoor navigation system for indoor robots by mounting a camera on the top of the room to get an overall view of the room. With that, processed the images to get an obstacle map of the room and to plan a path for the robot to guide it to the desired destination. And and the authors found that most of the indoor service robots are using a fixed path to navigate in the environment and also a very few uses sensors built in the robot to navigate which is also not an effective method as it does not include the overall configuration space when path planning as the sensors have a limited line-of-sight. This methodology presented in this paper will be an added advantage over other existing systems in the industry as it provides solution for sudden objects that come across the path by allowing the robot to re-request a new path after a waiting time allowing to check whether the object is moving away from the path. In future, authors plan to improve this with optimizing the path and to include prediction of moving obstacles and improving the efficiency in indoor path planning process.

4. REFERENCES

Anila, D. S., Saranya, B., Kiruthikamani, G., & Devi, P. (2017). INTELLIGENT SYSTEM FOR AUTOMATIC RAILWAY GATE CONTROLLING AND OBSTACLE DETECTION. 4(8), 8.

Connell, D., & Manh La, H. (2018). Extended rapidly exploring random tree–based dynamic path planning and replanning for mobile robots. International Journal of Advanced Robotic Systems, 15(3), 172988141877387. https://doi.org/10.1177/1729881418773874

Khanmirza, E., Haghbeigi, M., Nazarahari, M., & Doostie, S. (2017). A Comparative Study of Deterministic and Probabilistic Mobile Robot Path Planning Algorithms. 2017 5th RSI International Conference on Robotics and Mechatronics (ICRoM), 534–539. https://doi.org/10.1109/ICRoM.2017.8466197

Lavalle, S. M. (1998). Rapidly-Exploring Random Trees: A New Tool for Path Planning.

Li, I.-H., Chen, M.-C., Wang, W.-Y., Su, S.-F., & Lai, T.-W. (2014). Mobile Robot Self-Localization System Using Single Webcam Distance Measurement Technology in Indoor Environments. Sensors, 14(2), 2089–2109. https://doi.org/10.3390/s140202089

Mapping Camera Coordinates to a 2D Floor Plan. (n.d.). Retrieved October 20, 2019, from https://zbigatron.com/mapping-camera-coordinates-to-a-2d-floor-plan/

Milford, M., & Wyeth, G. (2010). Persistent Navigation and Mapping using a Biologically Inspired SLAM System. The International Journal of Robotics Research, 29(9), 1131–1153. https://doi.org/10.1177/0278364909340592

Noreen, I., Khan, A., & Habib, Z. (2016). A Comparison of RRT, RRT* and RRT*-Smart Path Planning Algorithms. 8.

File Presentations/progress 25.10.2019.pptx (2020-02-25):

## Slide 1

EE 74099 / EN 74099 Research Project

Progress Presentation For The Final Year Project
29.10.2019

Project title:
Order Management System And Vision Based Autonomous Delivery Robot For Restaurants

Members:
ANFM. Begum, GSU. Ahmadh & IIS. Prema Sri

Supervised by :
Dr. WGCW Kumara & Eng. MFM. Abdul Cader

Department of Electrical and Telecommunications Engineering
Faculty of Engineering
South Eastern University of Sri Lanka

## Content

1. Progress on the Robot Design and Control
2. Progress on Robot Path planning and Navigation
3. Next Steps

## Progress on the Robot Design and Control

## Robot Chassis Building


- We have finished the mechanical building of the robot design.
- Currently robot platform accepts navigation commands through Bluetooth.

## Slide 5


- Arduino Uno Microcontroller board
- TB6600 Stepper Motor Driver
- Ultrasonic Sensors
- Bluetooth Module


- NEMA 23 Stepper Motors
- Caster wheels
- 6000mAh Lipo Battery

## Building the robot


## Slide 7

Obstacle Detection


- Ultrasonic Sensors detects if any obstacles suddenly come across its path.
- Robot then send the current position to the navigation system for path regeneration.

## Communication Between Navigation System and Robot Platform

Sending Step Counts and rotation angles to move

Navigation System

Sending current position when obstacle is encountered for path regeneration

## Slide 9

Robot Movement

- Camera captures and generate path.
- Robot will navigate by receiving directions and step count from node to node.
- If an obstacle is detected by ultrasonic sensor, it will request for a new path from navigation system.

## Path planning and Navigation

## Camera

- Up to now, we have been experimenting with YI Action Camera
- We mounted the camera and took pictures of different occasions
- And then we processed the pictures with the algorithms to generate maps and so forth.

Image result for yi action camera"

## Path Planning

- Path Planning algorithm generates set of points from starting point to end point.
- We need to generate C++ code from MATLAB code for path planning algorithm to implement it on Jetson Nano platform.


## Next steps

## Next steps

- Implementation of calculations of navigation system
- Code Generation from Matlab and implementation on Jetson Nano

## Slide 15

Thank You

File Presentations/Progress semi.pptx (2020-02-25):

## Robot chassis design

- The design we choose should be able to hold electronics components such as microcontrollers, sensors, battery and hold food we need to deliver.
- One of the easiest designs to satisfy these requirements is TurtleBot, which has kind of table-like design.

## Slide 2


- It has three layers in the chassis.
- A robot platform called Roomba is the drive mechanism of this platform.
- We are planning to design a robot similar to this with our own moving platform and components.
- Moving platform will be designed as a differential drive system.

## Designing Robot model

- We did a Solidworks model for the Robot design we are planning to build.
- For the plates we decided to go with Aluminum Composite Material boards because of their strength and light weight.
- To connect plates we will be using threaded rods covered by aluminum tubes.


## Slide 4

- The choice of wheel types for a mobile robot is strongly linked to the choice of wheel arrangement, or wheel geometry.
- One of the cost-effective solution for mobile robot navigation is differential drive systems.


Source : semanticscholor.org

## Total Weight Estimation

Item | Weight
ACM Board for 0.378 m² area | 1.52 kg
Threaded rods for 3.5 m | 2.2 kg
Kinect | 0.6 kg
Aluminum tubes | 0.4 kg
Wheels | 0.6 kg
Power Bank and Battery | 1.0 kg
Motors (NEMA 23) x 2 | 1.2 kg
Other Electronics | 0.5 kg
For foods | 1.0 kg
Steel Bottom plate | 0.8 kg
Total Weight | 9.83 kg

## Calculation of motor torque

- In our design we have 4 wheels and 2 motors.
- Here we assume that the coefficient of friction is 0.6 and radius of wheel is 5 cm.
- The weight acting on the four wheels can be written as,

- N1 is the weight acting on each caster wheel.
- N2 on each motor wheel.

2 ∗ N1 + 2 ∗ N2 = Total Weight

The maximum torque is required when the robot starts moving. It should also overcome friction.
To calculate the maximum torque (T),

μ ∗ N ∗ r − T = 0

- μ is the coefficient of friction.
- N is the average weight acting on each wheel.
- r is the radius of wheels.
- T is the torque.

## Calculation of motor torque

- Assuming that the weight of the robot is equally distributed on all the four wheels,

N = mg / 4

=9.83kg ×9.8ms^(−2) / 4

=24.08 N

Motor torque required,

T = 0.6 ∗ 24.08N ∗ 0.05 m

= 0.722 N m

Reference - Learning Robotics using Python by Lentin Joseph

## Center of Gravity Calculation


P

W1 – Steel Bottom plate, Power bank, Battery and Other Electronics.

W2 – ACM Board, Treaded rods, Aluminum tubes Jetson Nano and Arduino.

W3 – ACM Board, Aluminum L profile and food.

W4 – Kinect and holding plate

W5 – Motors and wheels.

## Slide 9


W1 = 0.8 kg + 1 kg + 0.5 kg
= 2.3 kg x 9.8ms^(−2)
= 22.54 N

W2 = 0.5 kg + 2.2 kg + 0.4 kg + 0.136 kg + 0.05 kg
= 3.286 kg x 9.8ms^(−2)
= 32.20 N

W3 = 0.5 kg + 0.2 kg + 1.0 kg
= 1.7 kg x 9.8ms^(−2)
= 16.66 N

W4 = 0.6 kg + 0.15 kg
= 0.75 kg x 9.8ms^(−2)
= 7.35 N

W5 = 1.2 kg + 0.6 kg
= 1.8 kg x 9.8ms^(−2)
= 17.64 N

Wtotal = 2.3 kg + 3.286 kg + 1.7 kg + 0.75 kg + 1.8 kg
= 9.836 kg x 9.8ms^(−2)
= 96.39 N

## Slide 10


P

Considering the moments around point P in clockwise direction,

W1 x 0 + W2 x 0.3 m + W3 x 0.6 m + W4 x 0.5 m - W5 x 0.04m = Wtotal x X

22.54 N x 0 + 32.20 N x 0.3 m + 16.66 N x 0.6 m + 7.35 N x 0.5 m - 17.64 N x 0.04m = 96.39 N x X

9.66 Nm + 9.996 Nm + 3.675 Nm – 0.7 Nm = 96.39 N x X

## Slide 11

X = (22.631 Nm)/(96.39N)

X = 0.235 m

According to the calculation the Center of Gravity of the robot design is 0.235 m above the bottom plate. It is 9.1cm below the center.

## System Diagram


- User will put the order through the order management system.
- Order will be notified to the chef and chef will place the food on the robot food-placeholder once the order is ready.
- Order management system will send a message to the delivery robot to collect the food.
- Navigation system will then navigate the robot to the destination table and the customer on the table will take the food.

## Selection of motors, controllers and other electronics

Selected Motor – NEMA 17/23 Stepper Motor

- Holding torque - 1.02 / 0.53 Nm (Required 0.722 Nm )
- Step Angle - 1.8 ⁰
- Current - 3A / 1.5A


## Selection of motors, controllers and other electronics

Selected Motor Driver – TB6600 Stepper Motor Driver


- Output Current - up to 4.0A
- Micro Step - 1, 2/A, 2/B, 4, 8, 16,32

## Selection of motors, controllers and other electronics

Selected Controller – Arduino Uno


- Digital I/O Pins - 14
- Operating Voltage - 5V

## Selection of motors, controllers and other electronics

Selected Single Board Computer – Nvidia Jetson Nano

- Quad-core Arm A57 processor @ 1.43
- 4GB System Memory
- 4 x USB 3.0 ports, 1x USB 2.0 Micro-B port for power


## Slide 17

Thank You


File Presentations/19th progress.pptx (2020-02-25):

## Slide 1

EE 74099 / EN 74099 Research Project
Project Title: Vision Based Navigation System for Indoor Robots

Progress Presentation – 19
20.09.2019

Under the Supervision of :
Dr. WGCW Kumara
And Eng. Abdul Cadar

Team Members:
ANFM. Begum - SEU/IS/13/EG/002
GSU. Ahmadh - SEU/IS/13/EG/011
IIS. Prema Sri - SEU/IS/13/EG/032

## Content

1. Progress This Week
2. Order Management System – What we have done
  1. Introduction
  2. Home page
  3. Admin page
  4. Food ordering
  5. Database

## Progress This Week

As we discussed last week, We worked on OMS and here are the features we included in this.
We covered basic features to cover the purpose of our project.
Here they are,
1. For Customer,
  1. Food display
  2. Food Order and Table Select
2. For Administrator
  1. Get order details
  2. Mark order status (Processing, Delivered)
  3. Update Food in Database

## Introduction

- The Order Management System(OMS) is created to get the orders from the customer and track the progress of each order throughout the system.
- We developed the OMS using XAMPP software which contains,
1. Apache server (HTTP server)
2. MariaDB (database)
3. PHP (programming language)
- Now, we completed the OMS with new user interface and it can be access on local web server.

## Home page


- Home page mainly consists the food menu in which the customer can order their dishes by selecting the image of the dish.
- Dishes has been organized into several categories and each one can be ordered separately.
- Admin can access the website by login with valid credentials.

## Admin page

To access the database through the webpage, an admin page is created with the requirement of administrator credentials. New login credentials can be created by sign up within the admin page only. Admin can also logout anywhere in the admin page using the sign-out option.


## Admin page

- To maintain the orders, admin page has some following facilities,
1. Table plan:
Here status of each and every table can be given to the database which can help to display the available table for customers when they are trying to order the food and admin can track the order for the delivery and the payment.


## Admin page

2. Order details:
Here orders are displayed to know the dishes and their table number. Filter option is also provided to find out a specific detail.


## Food Ordering

- Customer can submit their order by selecting the amount of food and the table number and also they can receive success popup message. If they fail to submit then the error message can be displayed.


## Food Ordering

- Finally the ordering details can be updated in the database and admin page.


## Database

- We used the MariaDB database with local server 127.0.0.1
- Database has following tables to maintain the OMS.


1. admin
2. food_menu
3. orders
4. table plan
5. users

## Database

- Tables of the database is shown below,
1. admin:
Total number of tables in the restaurant is updated here.
2. food_menu:
Each and every food in the restaurant and their amount, price, and category is inserted here. According to this information, food menu including the image is prepared and displayed for the ordering.
3. orders:
Order with order id, table number, dishes and their amount is updated here. The order id will be the unique value for each customer for their payment and the other clarification. These details will be displayed in the admin page for delivery.

## Database

4. table plan:
The availability of the table is updated here through by the admin. It has the status of the table whether it is open or occupied, payment whether it is paid or not and the food delivery whether it is delivered or not.
5. users:
Validate user name and password to access the admin page is updated here.

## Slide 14

Thank You

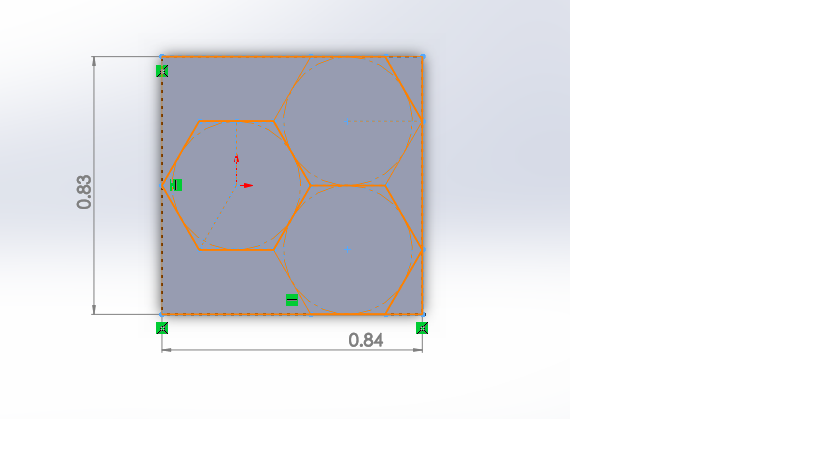
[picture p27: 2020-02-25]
Hardware/Robot_design/plate1.png

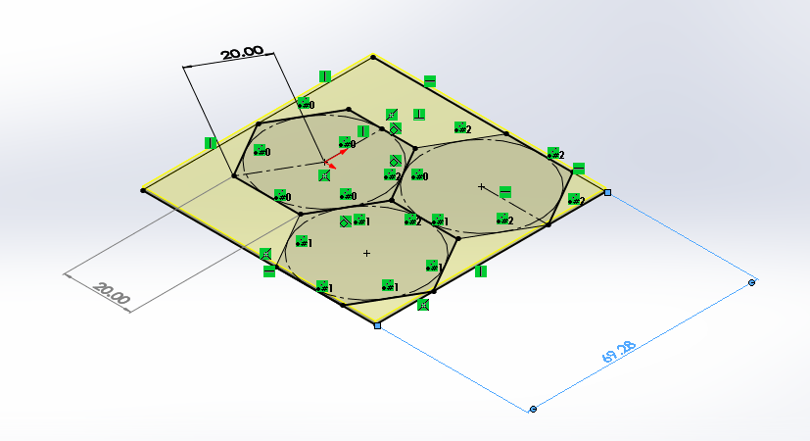
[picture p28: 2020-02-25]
Hardware/Robot_design/plates all.png

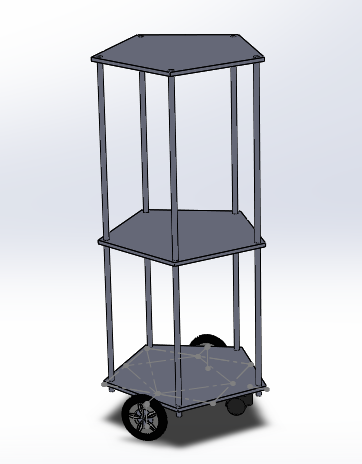
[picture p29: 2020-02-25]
Hardware/Robot_design/full_body.png

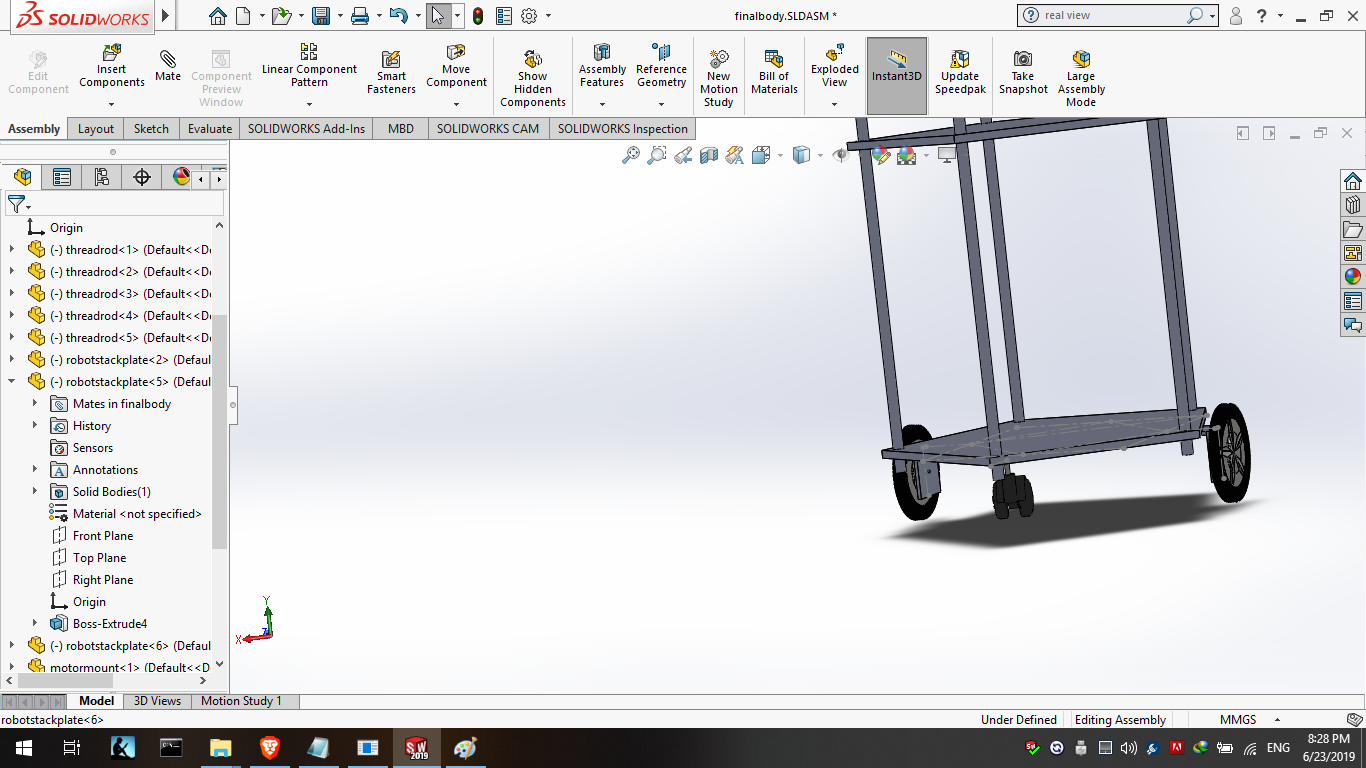
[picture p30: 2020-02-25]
Hardware/Robot_design/designing.png

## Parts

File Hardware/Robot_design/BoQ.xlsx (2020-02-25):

Desc | Item |  | Qty | Price
Top Plate | Aluminum-L profile | 6x20 cm | 120 cm
 | Nuts and bolts for mounting | 2x6 nut and bolt pair | 12
Plates | 3x 40cm hex ACM plates | 1x1 meter plate | 1msq
Skeleton | Threaded rod - 12mm | 6x70 cm | 420 cm
 | Nuts | 36 x 12mm nuts + 14 addition | 50 NUTS
 | Aluminum tubes |  | 420 cm
bottom body | L profile -steel | 6x20 cm | 120 cm
 | hex - metal sheet | 40x40 cm square | 1600cmsq
 | Motor couple - To be decided | 2 | 2
 | Motor mount - To be decided | 2 | 2
 | Wheels - To be decided | 2 | 2
 | Wheel bearings -To be decided | 2x2 | 4
Misc | spacers
 | nuts
 | cable ties

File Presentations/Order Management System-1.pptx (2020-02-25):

## Introduction

- Our project is about how to make a path planning and navigation of autonomous robot for indoor environment.
- There are the following difficulties in achieving this,
1. navigate the robot to its destination without colliding obstacles.
2. keep track of obstacles in the robot’s path because of other obstacles in the whole environment.
- To get rid of these problems, we are going to use external cameras mounted on the room tops.

## Objective

- Main purpose:
Having a navigation system for internal robots by directing it with an external vision to oversee the entire navigation area.
- In order to achieve this, we are going to deal with our project into three parts as below,
1. Customer order management system
2. External vision based path planning
3. Robot’s hardware and control system

## 1. Order Management System

- User interaction can be given via handheld device at the table.
- For the purpose for creating web application, we have to deal with a scripting language(PHP), a web server(Apache) and a database(MySQL). Now we are using XAMPP which is combined with X-OS (cross platform), Apache, MySQL and PHP.

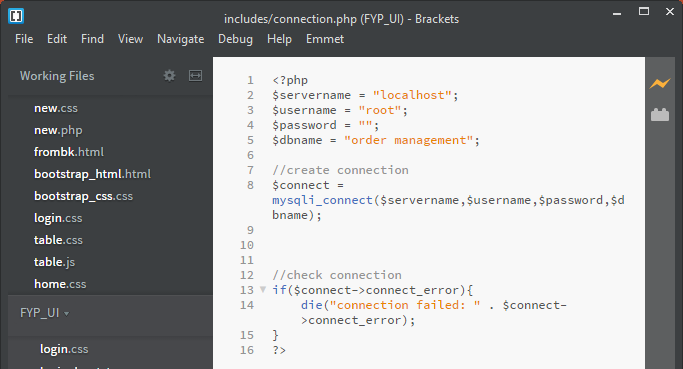
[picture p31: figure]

Figure 1: Php code to make connection
to server

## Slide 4

- Webpage mainly deals with the admin interface for kitchen administration and the user interface for customer to utilize ordering. Login page decides who will be going to use the web application.
- User can go for ordering page by tapping “Order” menu while admin can login through by tapping “Admin” menu.

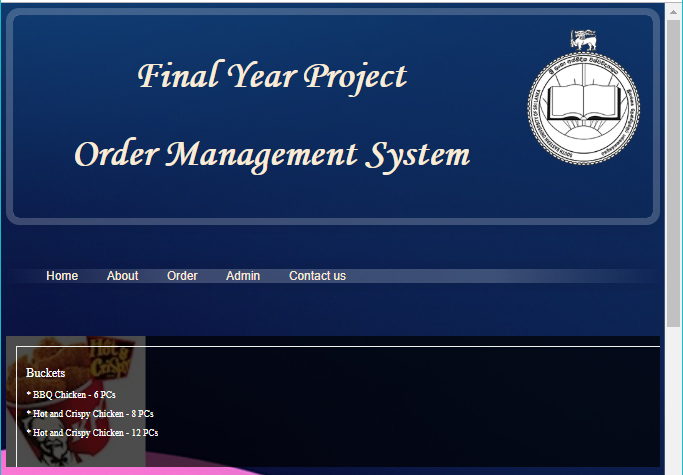
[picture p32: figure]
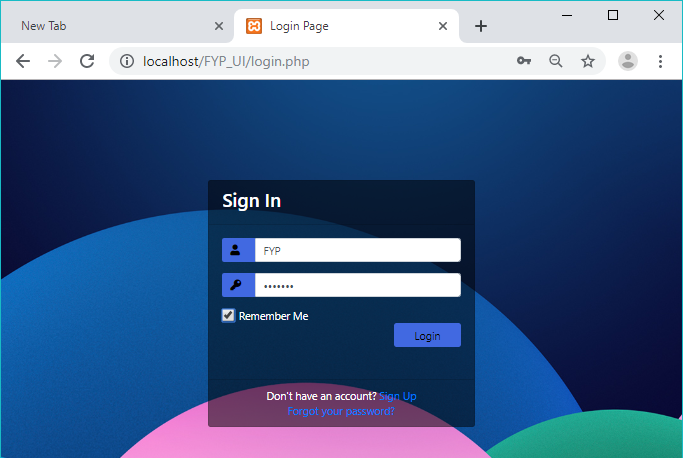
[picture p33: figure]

Figure 3: login window for enter to the administration page

Figure 2: Home page

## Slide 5

- Admin can update their valid username and password in database. Hence no one can enter the admin page by login. If we enter the correct password server will check the details in database and it will allow to the admin page.

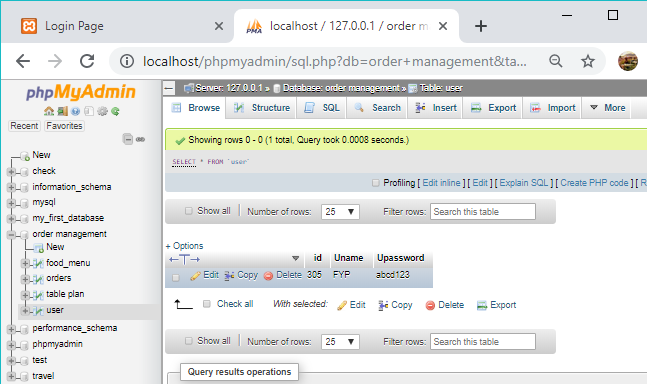
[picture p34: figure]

Figure: login data in the database

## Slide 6

- Admin should be responsible for updating the food availability and the order details in the database. Then it will be shown in customer’s ordering page.

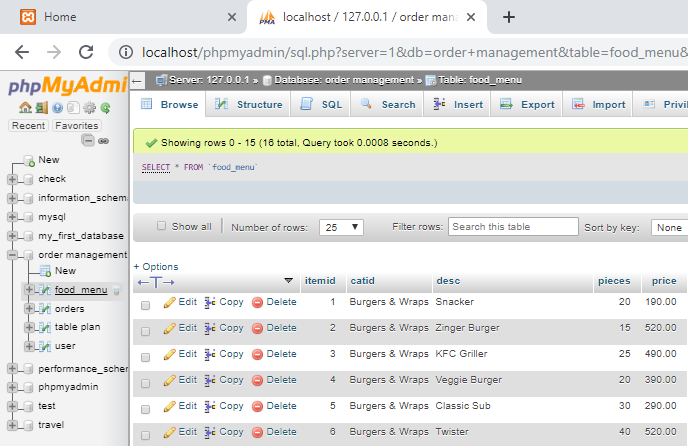
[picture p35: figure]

Figure: food available list in the database

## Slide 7

- Selected foods by customer can be send through the admin page by getting data from database.

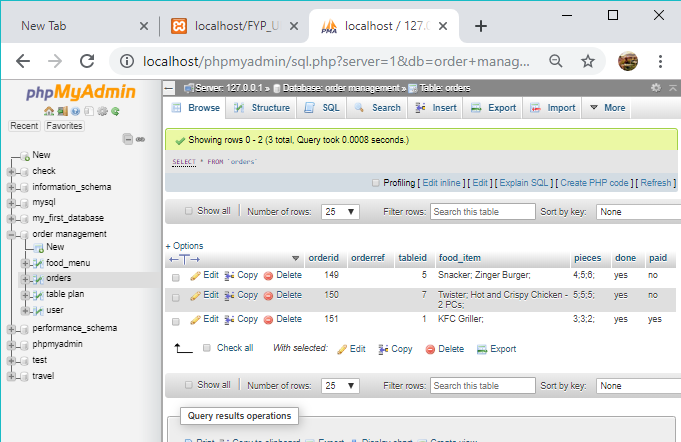
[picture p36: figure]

Figure 4: food order list in the database

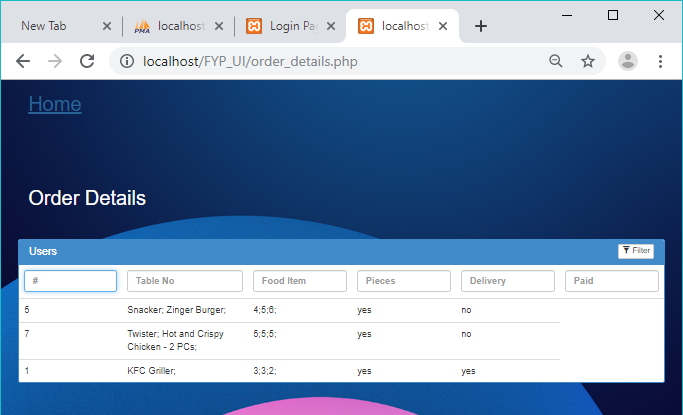
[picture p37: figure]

Figure 5: food order list in the user window

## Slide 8

- User interface can be used for ordering the food, table reservation and payment.
- Admin interface can be used for order updates, food availability and will give notification to the robot.
- Until now, we finished the following tasks,
- Create Interface for customer and admin
- Receive order from webpage and update it in database
- Connect database to the webpage and update the orders in admin page
- We try to complete the OMS with some features as given below,
- Organize the webpage for payment
- Track the status of the order

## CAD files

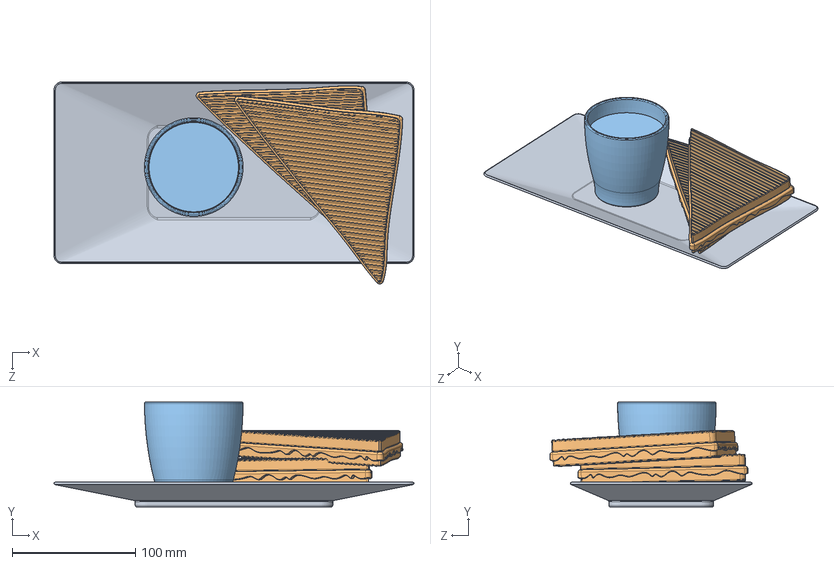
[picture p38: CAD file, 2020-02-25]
Hardware/Robot_design/grilled-cheese-plate-1.snapshot.2/Grilled Cheese Plate.SLDASM
292.0 x 85.0 x 163.9 mm
Plate
Grilled Cheese x 4
Gaspatxo

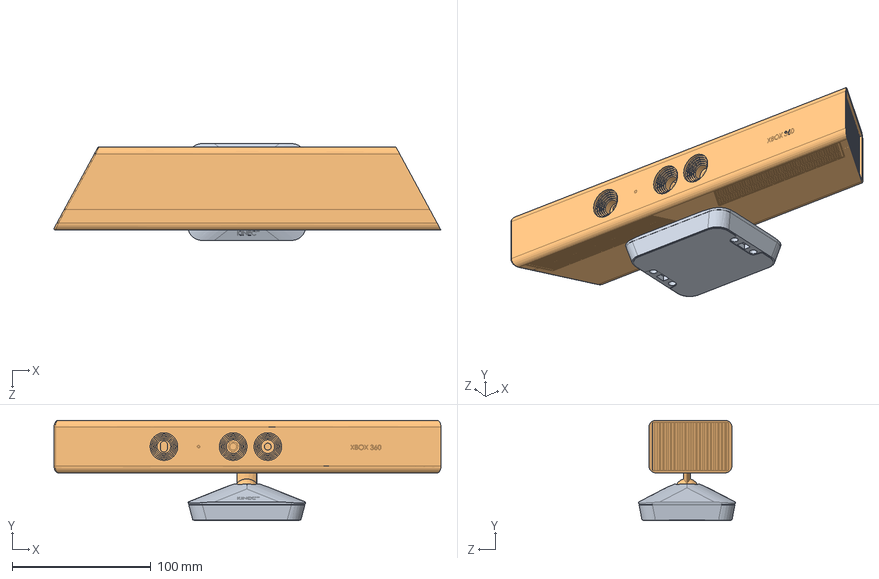
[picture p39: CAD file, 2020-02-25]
Hardware/Robot_design/kinect-1.snapshot.2/final kinect.SLDASM
279.3 x 72.5 x 70.0 mm
lower part
kinect upper part

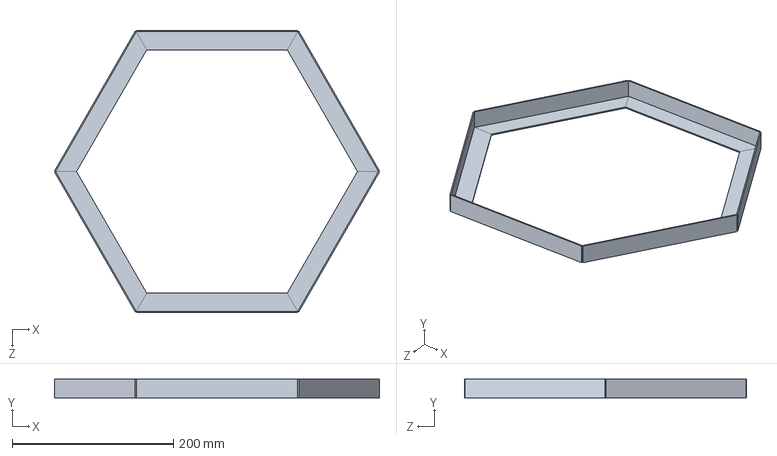
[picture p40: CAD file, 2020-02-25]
Hardware/Robot_design/bottom/Assem1.SLDASM
402.6 x 23.0 x 349.4 mm
l-bottom x 6

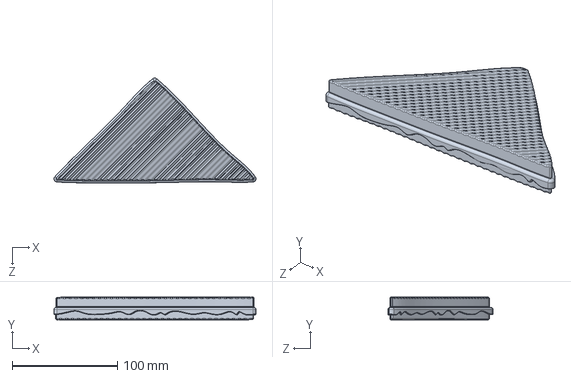
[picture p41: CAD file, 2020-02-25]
Hardware/Robot_design/grilled-cheese-plate-1.snapshot.2/Grilled Cheese.SLDASM
192.1 x 21.8 x 99.7 mm
Grilled Cheese x 2

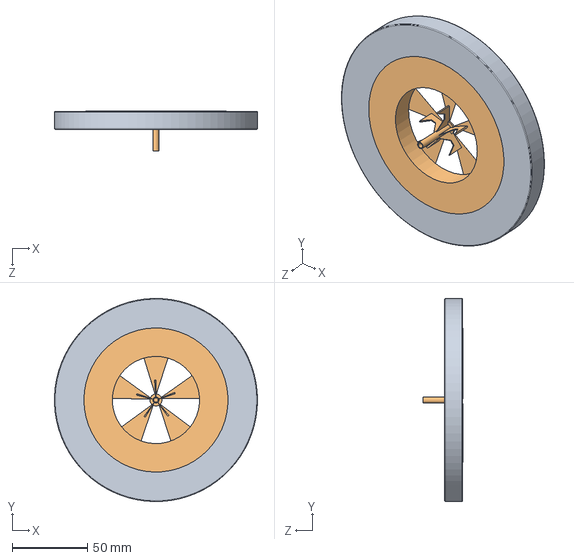
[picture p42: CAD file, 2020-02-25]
Hardware/Robot_design/roue.SLDASM
134.9 x 135.0 x 26.8 mm
tire
disque roue

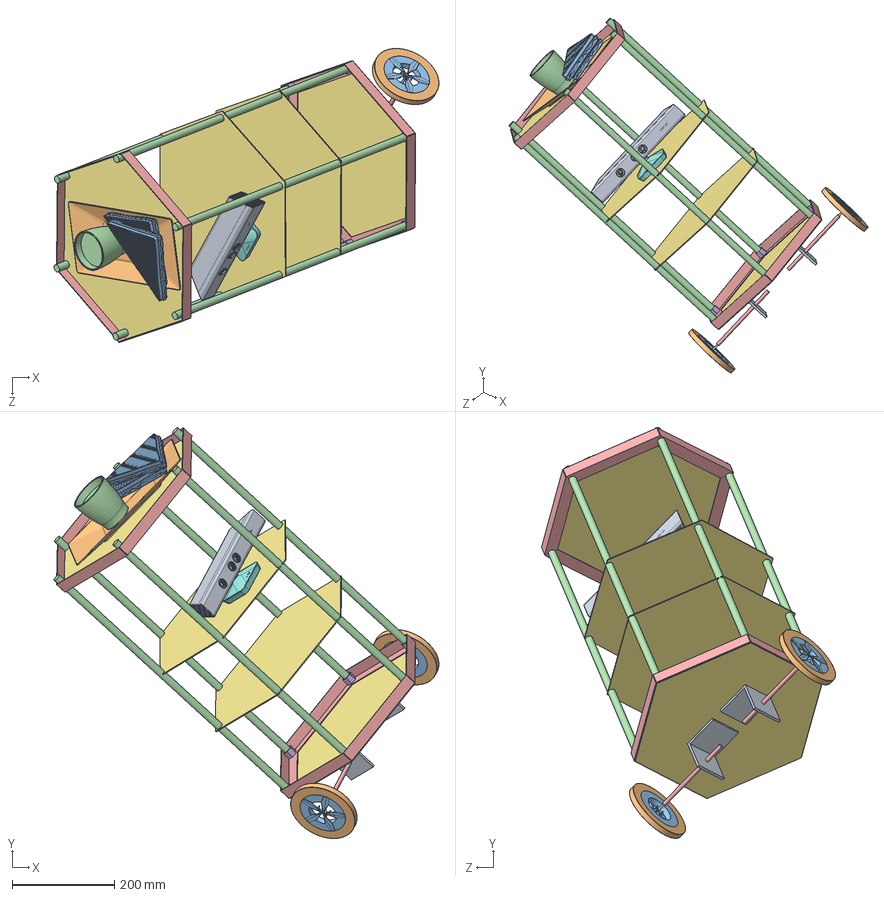
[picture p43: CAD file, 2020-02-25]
Hardware/Robot_design/complete_hex_bot.SLDASM
752.8 x 803.8 x 575.1 mm
motormount x 2
tire x 2
disque roue x 2
threadrod x 6
l-bottom x 12
hex_nut x 18
hex-plate x 4
lower part
kinect upper part
Plate
Grilled Cheese x 4
Gaspatxo
wheel_shaft x 2

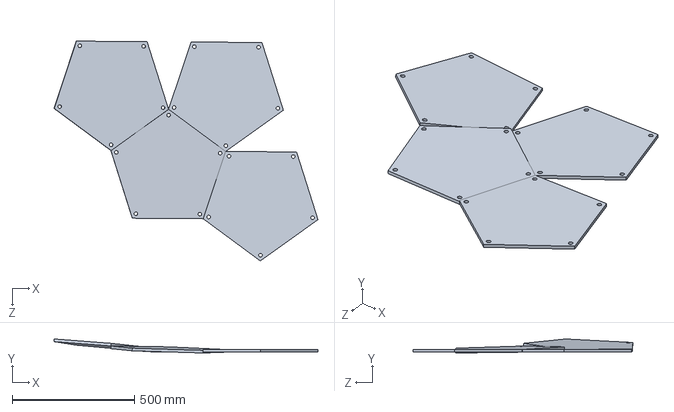
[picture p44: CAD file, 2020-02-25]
Hardware/Robot_design/ACMboard.SLDASM
1081.2 x 57.5 x 900.2 mm
robotstackplate x 4

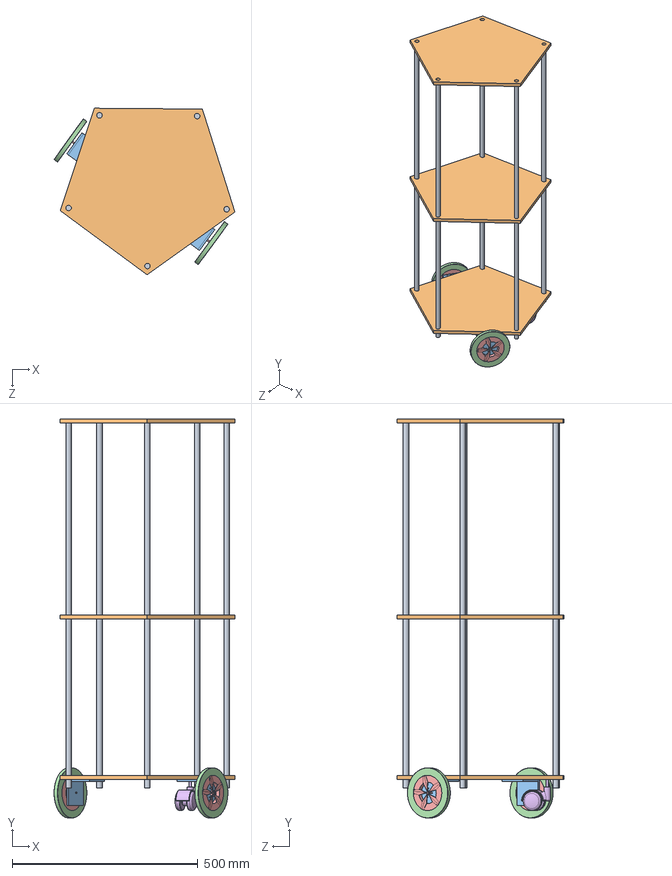
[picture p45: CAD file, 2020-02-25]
Hardware/Robot_design/finalbody.SLDASM
486.8 x 1073.9 x 448.3 mm
threadrod x 5
robotstackplate x 3
motormount x 2
tire x 2
disque roue x 2
2 inch caster wheel

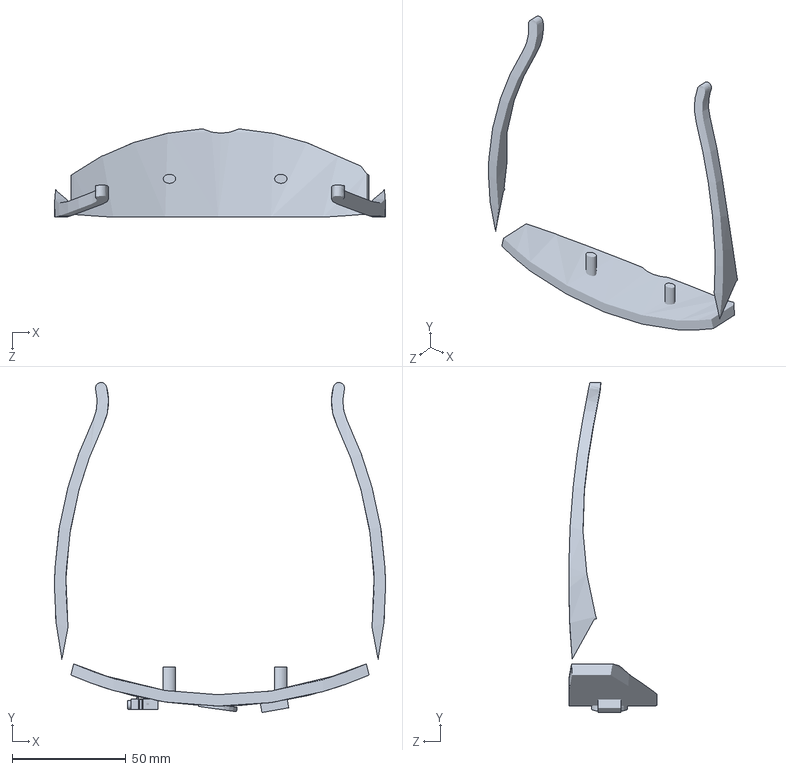
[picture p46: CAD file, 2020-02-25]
Hardware/Robot_design/bottom/mock up.SLDPRT
145.6 x 145.2 x 38.9 mm

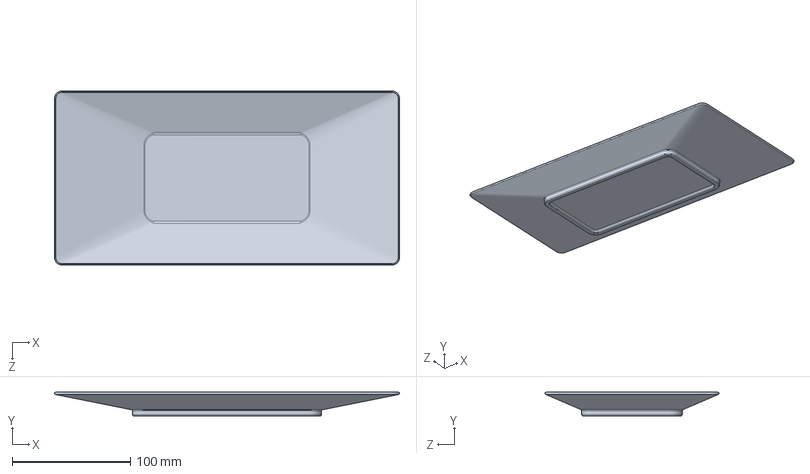
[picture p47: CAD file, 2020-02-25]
Hardware/Robot_design/grilled-cheese-plate-1.snapshot.2/Plate.SLDPRT
292.0 x 20.0 x 147.3 mm

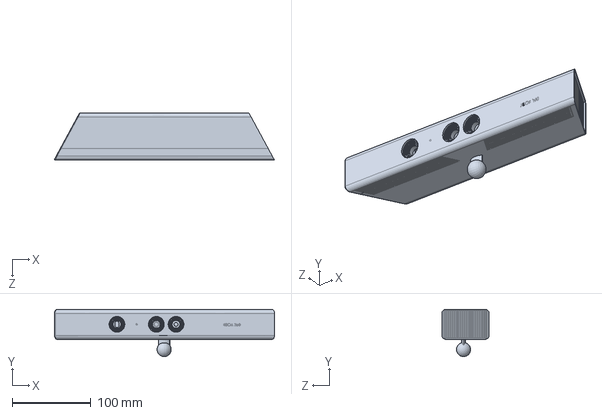
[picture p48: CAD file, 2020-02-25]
Hardware/Robot_design/kinect-1.snapshot.2/kinect upper part.SLDPRT
279.3 x 60.0 x 60.0 mm

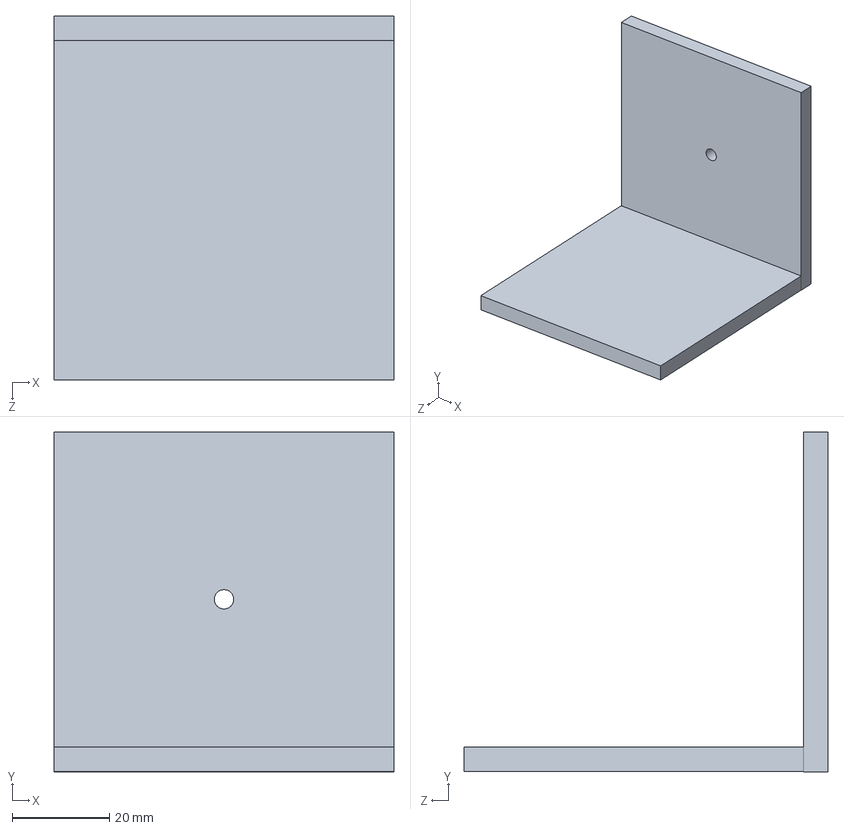
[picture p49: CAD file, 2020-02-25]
Hardware/Robot_design/motormount.SLDPRT
70.0 x 70.0 x 75.0 mm

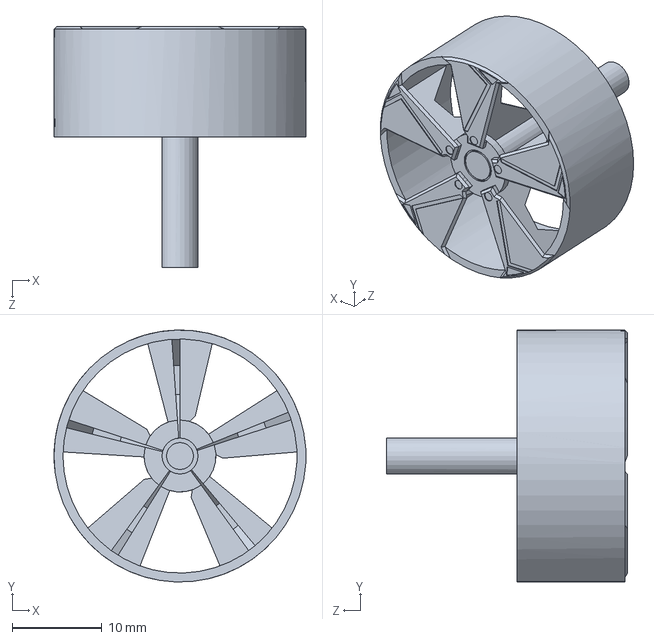
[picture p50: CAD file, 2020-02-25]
Hardware/Robot_design/wheel/Renderings/disque roue.SLDPRT
28.0 x 28.0 x 26.8 mm

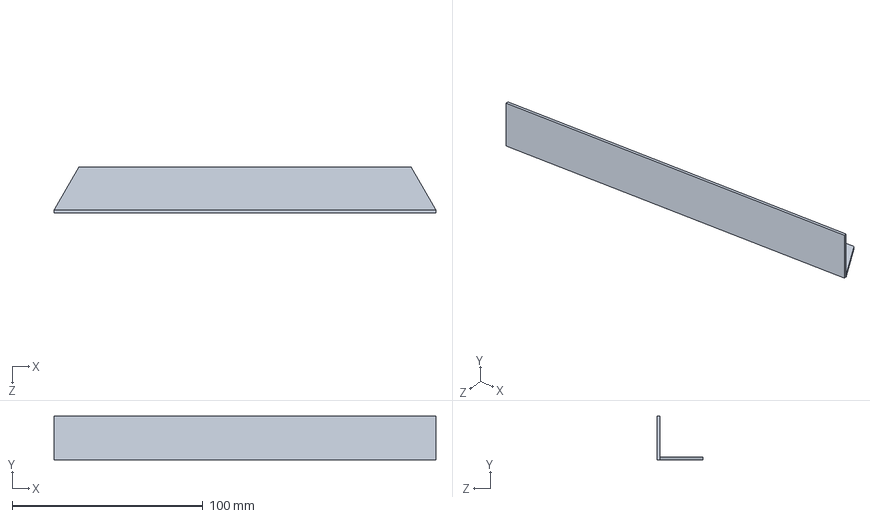
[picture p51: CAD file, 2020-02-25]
Hardware/Robot_design/bottom/l-bottom.SLDPRT
200.0 x 23.0 x 24.0 mm

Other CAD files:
Hardware/Robot_design/kinect-1.snapshot.2/lower part.SLDPRT
Hardware/Robot_design/wheel/Renderings/roue.STEP
Hardware/Robot_design/wheel_shaft.SLDPRT
Hardware/Robot_design/bottom/hex-plate.SLDPRT
Hardware/Robot_design/2 inch caster wheel.SLDPRT
Hardware/Robot_design/Part1.SLDPRT
Hardware/Robot_design/Part2.SLDPRT
Hardware/Robot_design/bottom/Glasses 3 (1).SLDPRT
Hardware/Robot_design/disque roue.SLDPRT
Hardware/Robot_design/grilled-cheese-plate-1.snapshot.2/Gaspatxo.SLDPRT
Hardware/Robot_design/grilled-cheese-plate-1.snapshot.2/Grilled Cheese.SLDPRT
Hardware/Robot_design/hex_nut.SLDPRT
Hardware/Robot_design/kinect_stand.SLDPRT
Hardware/Robot_design/robotstackplate.SLDPRT
Hardware/Robot_design/threadrod.SLDPRT
Hardware/Robot_design/tire.SLDPRT
Hardware/Robot_design/triple_hex_nut.SLDASM
Hardware/Robot_design/wheel/Renderings/roue.IGS
Hardware/Robot_design/wheel/Renderings/roue.SLDASM
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

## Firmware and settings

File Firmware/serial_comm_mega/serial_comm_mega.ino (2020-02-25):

#include <AccelStepper.h>
#include <MultiStepper.h>
#include <ArduinoJson.h>


//Stepper motor configuration and object creation
//pul, dir
//3,2
//6,5
AccelStepper stepper1(AccelStepper::FULL2WIRE, 6, 5);
AccelStepper stepper2(AccelStepper::FULL2WIRE, 8, 7);
MultiStepper steppers;

int attempt = 1;  //attempt of obsacle scanning.
int stepCount = 0;
int stepRight = 0;
int stepLeft = 0;
const int obstacleAlertPin = 4;
bool alreadyWaited = 0;



void generateReplyMessage(int cmd, float x, float y, int angle) {
  delay(10);
  DynamicJsonDocument  doc(200);
  //cmd=1 : Regeneration request
  //cmd=0 : Navigation completed
  doc["cmd"] = cmd;
  doc["x"] = x;
  doc["y"] = y;
  doc["deg"] = angle;
  Serial.println(serializeJson(doc, Serial2));
  // Serial2.println(serializeJson(doc, Serial));
  //return serializeJson(doc, Serial);
}





//LiquidCrystal_I2C lcd(0x27, 16, 2); // set the LCD address to 0x27 for a 16 chars and 2 line display
int num_of_data;





void receiveCommand() {
  // Serial.println("Going to read");
  String buff;
  if (Serial2.available()) {
    buff = Serial2.readString();
    //Serial2.println("Hi How are you?");
    //Serial.println("got something here");
    Serial.println(buff);

    data2arrays(buff);
  }
  //  Serial2.println("I received the following from you");
  // Serial2.println(buff);
}

void pathRegenerateRequest(float x, float y, int deg) {
  generateReplyMessage(1, x, y, deg);
  receiveCommand();
}

int stepperPosition(int rightStep, int leftStep) {
  long positions[2];
  positions[0] = -rightStep;  //negate the movement direction
  positions[1] = -leftStep; //negate the movement direction
  steppers.moveTo(positions);
  steppers.runSpeedToPosition();
}

int stepCountCalc(int type, int value) {
  if (type == 0) { //Straight Movement to centimeters
    stepCount = round((value + 0.1 * value) * 360 * 8 / (1.8 * 1.8 * 6));

  }
  else if (type == 1) { //Rotation to Angle

    stepCount = round((12975 / 180) * value);
  }

  return stepCount;
}





void data2arrays(String pld4mnivi) {
  DynamicJsonDocument doc(1024);
  DeserializationError error = deserializeJson(doc, pld4mnivi);
  if (error) {
    Serial.print(F("deserializeJson() failed: "));
    Serial.println(error.c_str());
    return;
  }
  num_of_data = doc["num"];
  int angle_data[num_of_data];
  int dis_data[num_of_data];

  for (int i = 0; i < num_of_data; i++) {

    angle_data[i] = doc["angle"][i];
    dis_data[i] = doc["distance"][i];
  }


  stepper1.setCurrentPosition(0);
  stepper2.setCurrentPosition(0);


  Navigate(angle_data, dis_data);

}




void Navigate(int angle_ar[], int dis_ar[]) {
  float Xdistance = 0;  //mur
  float Ydistance = 0;  //mur
  int FAngle = 0;  //mur
  for (int j = 0; j < num_of_data; j++) {
    int type, value;
    type = 0;
    value = 0;

    //rotating angle has no issue
    stepper1.setCurrentPosition(0);
    stepper2.setCurrentPosition(0);
    type = 1;
    stepRight = stepCountCalc(type, angle_ar[j]);
    stepLeft = -stepRight;
    stepperPosition(stepRight, stepLeft);
    delay(1000);


    //go straight only if there is no obstacle

    //going straight need t be sliced
    stepper1.setCurrentPosition(0);
    stepper2.setCurrentPosition(0);
    type = 0;    //straight mode is on

    int slice_length = 15; // dliving to this distance
    int numberOfSlices = dis_ar[j] / slice_length; //going straight in slices this number of time
    int remainingSliceLength = dis_ar[j] % slice_length; //going straight for the remaining


    if (dis_ar[j] > slice_length) {
      for (int slice_loop = 0; slice_loop < numberOfSlices; slice_loop++) { //going straight in slices this number of time
        alreadyWaited = 0;
        while ( digitalRead(obstacleAlertPin) == HIGH && alreadyWaited == 0 ) {
          delay(3000);
          alreadyWaited = 1;
        }

        if (digitalRead(obstacleAlertPin) == HIGH) {
          for (int angle_index = j; angle_index >= 0; angle_index--) {  //mur
            FAngle += angle_ar[angle_index];
          }
          //pathRegenerateRequest();
          pathRegenerateRequest(round(Xdistance), round(Ydistance), FAngle % 360);
        }

        else {

          stepper1.setCurrentPosition(0);
          stepper2.setCurrentPosition(0);
          stepRight = stepCountCalc(type, slice_length);
          stepLeft = stepRight;
          stepperPosition(-stepRight, -stepLeft);

          Xdistance += slice_length * sin(angle_ar[j] * PI / 180); //mur
          Ydistance += slice_length * cos(angle_ar[j] * PI / 180); //mur
          // delay(100);   //for debugging
        }

      }
      //going straight for the remaining
      if (remainingSliceLength != 0) {
        alreadyWaited = 0;

        while ( digitalRead(obstacleAlertPin) && alreadyWaited == 0 ) {

          delay(3000);
          alreadyWaited = 1;
        }

        if (digitalRead(obstacleAlertPin)) {
          for (int angle_index = j; angle_index >= 0; angle_index--) {  //mur
            FAngle += angle_ar[angle_index];
          }
          pathRegenerateRequest(round(Xdistance), round(Ydistance), FAngle % 360);  //mur
        }

        else {

          stepper1.setCurrentPosition(0);
          stepper2.setCurrentPosition(0);
          stepRight = stepCountCalc(type, remainingSliceLength);
          stepLeft = stepRight;
          stepperPosition(-stepRight, -stepLeft);
          Xdistance += remainingSliceLength * sin(angle_ar[j] * PI / 180); //mur
          Ydistance += remainingSliceLength * cos(angle_ar[j] * PI / 180); //mur
          // delay(100);   //for debugging

        }
      }
    }

    else {

      alreadyWaited = 0;
      while ( digitalRead(obstacleAlertPin) == HIGH && alreadyWaited == 0 ) {
        delay(3000);
        alreadyWaited = 1;
      }

      if (digitalRead(obstacleAlertPin) == HIGH) {
        for (int angle_index = j; angle_index >= 0; angle_index--) {  //mur
          FAngle += angle_ar[angle_index];
        }
        pathRegenerateRequest(round(Xdistance), round(Ydistance), FAngle % 360);  //mur

      }

      else {
        stepper1.setCurrentPosition(0);
        stepper2.setCurrentPosition(0);
        stepRight = stepCountCalc(type, dis_ar[j]);
        stepLeft = stepRight;
        stepperPosition(-stepRight, -stepLeft);

        Xdistance += dis_ar[j] * sin(angle_ar[j] * PI / 180); //mur
        Ydistance += dis_ar[j] * cos(angle_ar[j] * PI / 180); //mur
      }
    }
  }
  generateReplyMessage(0, 0, 0, 0);
  receiveCommand();
}






void setup()
{
  //  lcd.init();                      // initialize the lcd
  Serial.begin(9600);
  Serial2.begin(9600);
  pinMode(obstacleAlertPin, INPUT);
  stepper1.setMaxSpeed(1000);
  stepper2.setMaxSpeed(1000);
  steppers.addStepper(stepper1);
  steppers.addStepper(stepper2);
}


void loop()
{
  // read from port 1, send to port 0:
  /*if (Serial1.available()) {
    int inByte = Serial1.read();
    Serial.write(inByte);
    }*/

  // read from port 0, send to port 1:
  receiveCommand();
}

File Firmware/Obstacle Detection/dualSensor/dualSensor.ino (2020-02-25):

const int pingPin1 = 6; // Trigger Pin of Ultrasonic Sensor
const int echoPin1 = 7; // Echo Pin of Ultrasonic Sensor
const int pingPin2 = 9; // Trigger Pin of Ultrasonic Sensor
const int echoPin2 = 10; // Echo Pin of Ultrasonic Sensor
const int alertPin = 5;
const int alertLEDPin = 3;

const int limitDistance = 40;
long getDistance1() {
  long duration, inches, cm1;
  pinMode(pingPin1, OUTPUT);
  digitalWrite(pingPin1, LOW);
  delayMicroseconds(2);
  digitalWrite(pingPin1, HIGH);
  delayMicroseconds(10);
  digitalWrite(pingPin1, LOW);

  duration = pulseIn(echoPin1, HIGH);
  //  inches = microsecondsToInches(duration);
  cm1 = microsecondsToCentimeters(duration);

  return cm1;
}


long getDistance2() {
  long duration, inches, cm2;
  pinMode(pingPin2, OUTPUT);
  digitalWrite(pingPin2, LOW);
  delayMicroseconds(2);
  digitalWrite(pingPin2, HIGH);
  delayMicroseconds(10);
  digitalWrite(pingPin2, LOW);

  duration = pulseIn(echoPin2, HIGH);
  //  inches = microsecondsToInches(duration);
  cm2 = microsecondsToCentimeters(duration);

  return cm2;
}

void setup() {
  Serial.begin(9600); // Starting Serial Terminal
  pinMode(alertPin, OUTPUT);
  pinMode(alertLEDPin, OUTPUT);
}

void loop() {

  pinMode(echoPin1, INPUT);
    pinMode(echoPin2, INPUT);
  long dist1 = getDistance1();
  long dist2 = getDistance2();
//  while (dist1 <= limitDistance || dist2 <= limitDistance ) {
  while (dist1 <= limitDistance) {

    digitalWrite(alertPin, HIGH);
    digitalWrite(alertLEDPin, HIGH);
    Serial.print(getDistance1());
    Serial.print("cm");
    Serial.println();
    Serial.print(getDistance2());
    Serial.print("cm");
    Serial.println();
    dist1 = getDistance1();
    dist2 = getDistance2();
  }
  
  digitalWrite(alertPin, LOW);
  digitalWrite(alertLEDPin, LOW);
  Serial.print(getDistance1());  
  Serial.print("cm");
  Serial.println();
  Serial.print(getDistance2());
  Serial.print("cm");
  Serial.println();
  delay(10);
}



long microsecondsToCentimeters(long microseconds) {
  return microseconds / 29 / 2;
}
